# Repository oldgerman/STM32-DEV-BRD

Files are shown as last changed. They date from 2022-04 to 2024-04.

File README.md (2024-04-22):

# STM32-DEV-BRD

（白嫖失败血压升高后）整的几片考究的STM32最小系统板，~~清一色0603~~，确保食用舒适

PCB工程完全开源，提供测试程序，焊接后第一时间可刷入测试

## 型号

- 💚：完工并已验证
- :yellow_heart:：完工但未验证
- :x:：还没画板子

| 更新日期 | 状态 | 开发板型号 | 支持芯片 | PCB层数 |
| --- | --- | --- | --- | --- |
| 2022/04/29 | 💚 | [G031 DEV BRD](https://github.com/oldgerman/STM32-DEV-BRD/tree/master/G031_Dev) | STM32G031G8Ux | 2 |
| 2022/04/29 | 💚 | [F4x1 DEV BRD](https://github.com/oldgerman/STM32-DEV-BRD/tree/master/F4x1_Dev) | STM32F401CxUx<br />STM32F411CxUx | 4 |
| 2022/07/31 | :yellow_heart: | [H7xxVxT6_LANG](https://github.com/oldgerman/STM32-DEV-BRD/tree/master/H7xxVxT6_LANG) | （LQFP100）<br />STM32H750<br />STM32H743<br />STM32H7B0 | 2 |
| ? | :x: | F07x DEV BRD | STM32F071CxUx<br />STM32F072CxUx | ? |
| ? | :x: | F103 DEV BRD | STM32F103CxUx | ? |
| 2024/02/29 | 💚 | [G431 DEV BRD](https://github.com/oldgerman/STM32-DEV-BRD/tree/master/G431_Dev) | STM32G431GBUx | 4 |
| ? | ... | （不定期更新） | | |

## PCB

| 开发板型号 | Top | Bottom |
| --- | --- | --- |
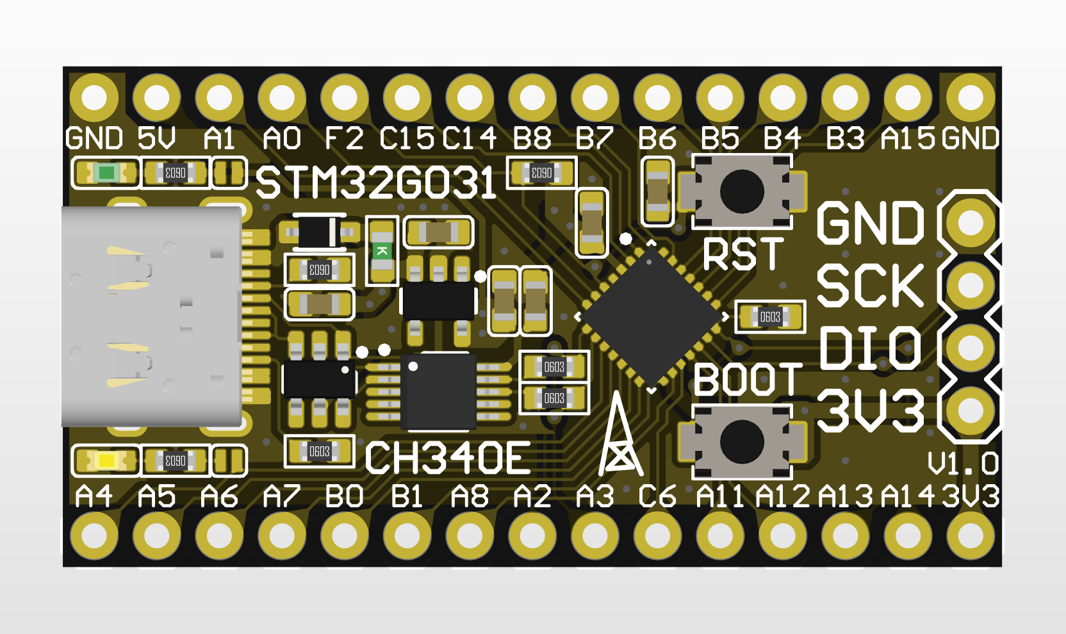
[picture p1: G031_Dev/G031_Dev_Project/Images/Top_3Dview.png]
Top_3Dview
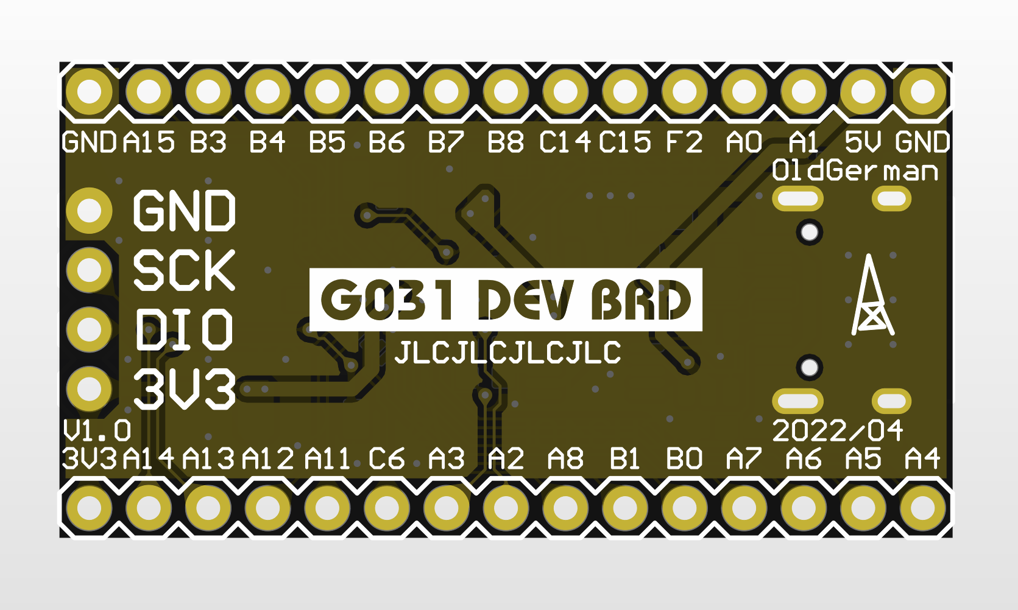
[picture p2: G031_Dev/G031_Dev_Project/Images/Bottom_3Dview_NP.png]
Bottom_3Dview_NP
| G031 DEV BRD |  |  |
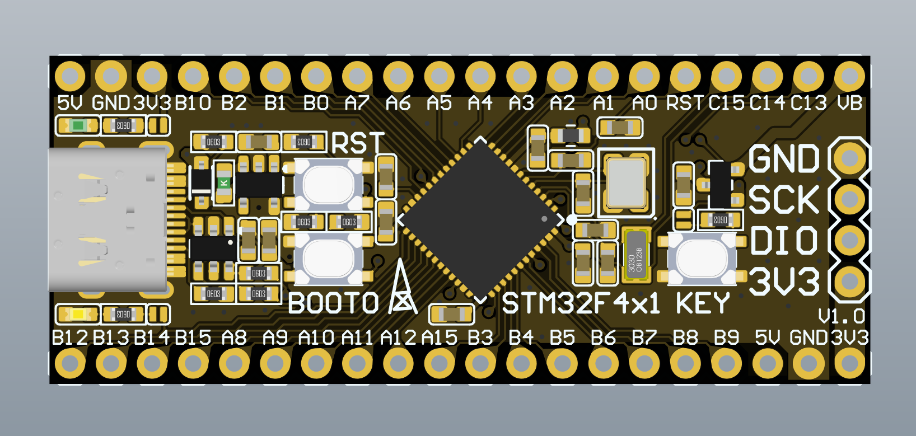
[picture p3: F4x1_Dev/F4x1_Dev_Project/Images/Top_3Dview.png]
Top_3Dview
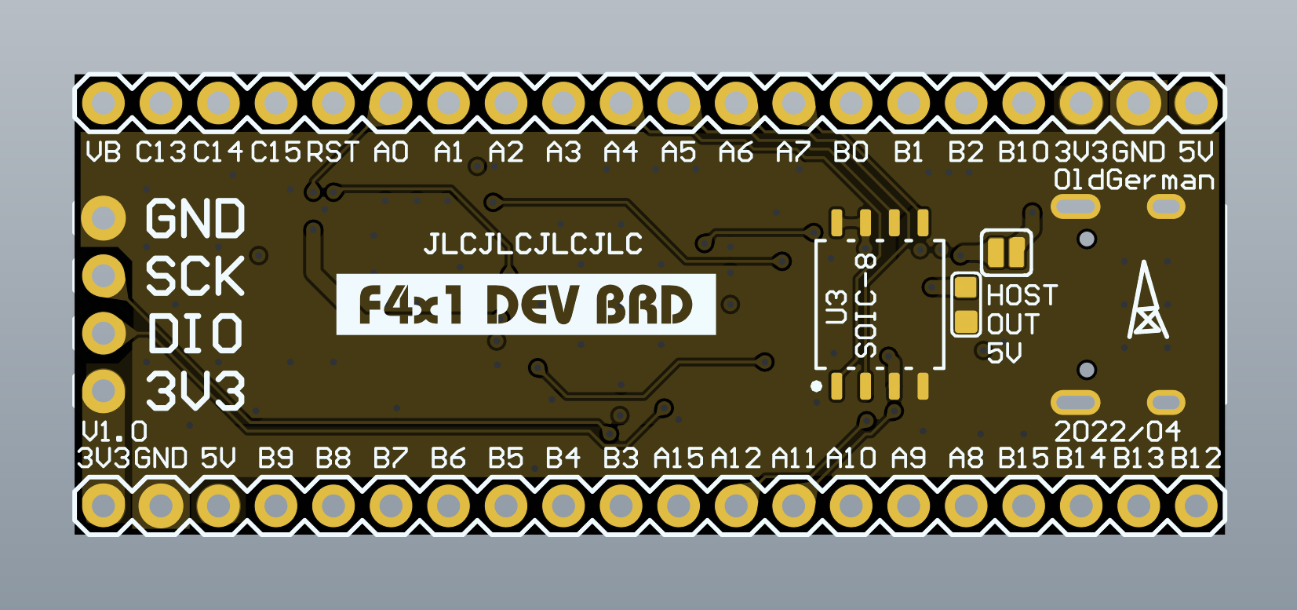
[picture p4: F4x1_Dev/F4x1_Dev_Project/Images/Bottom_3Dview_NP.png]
Bottom_3Dview_NP
| F4x1 DEV BRD |  |  |
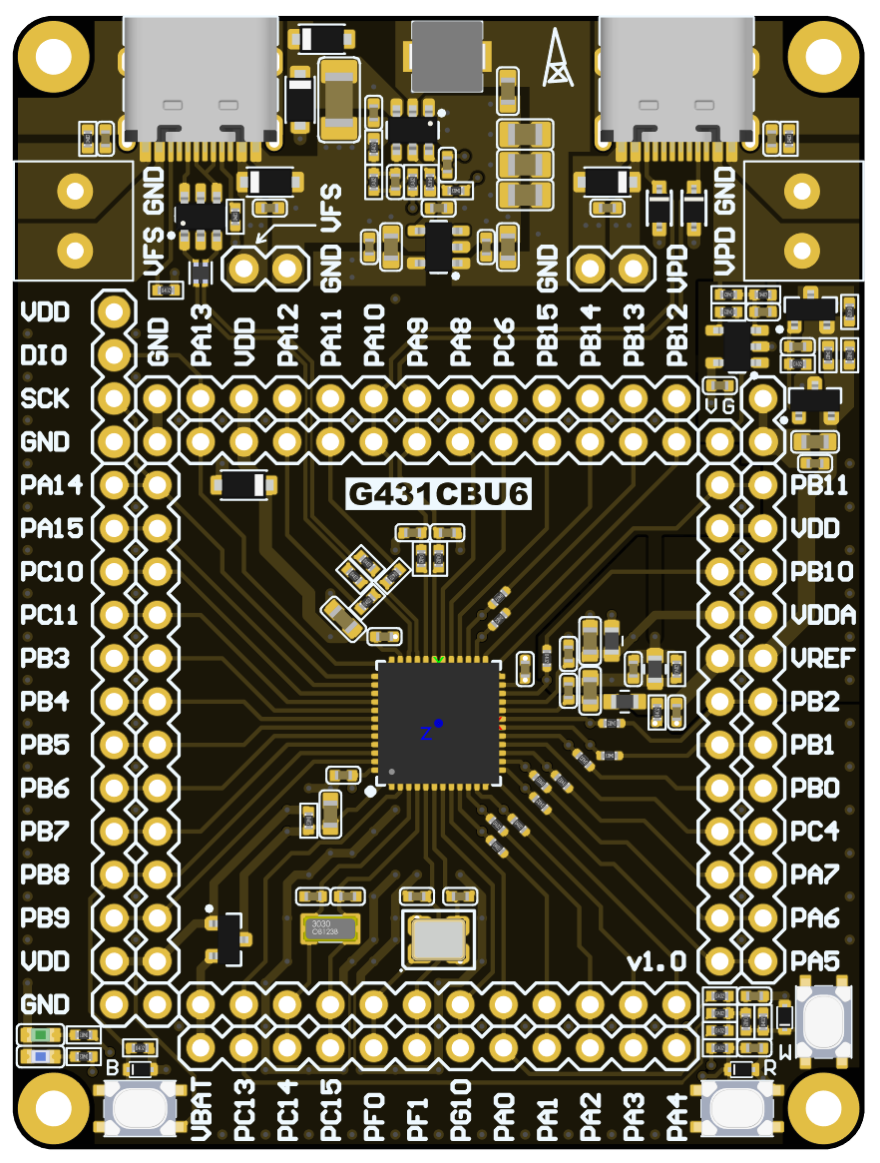
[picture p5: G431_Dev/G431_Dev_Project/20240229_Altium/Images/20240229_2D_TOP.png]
20240229_2D_TOP
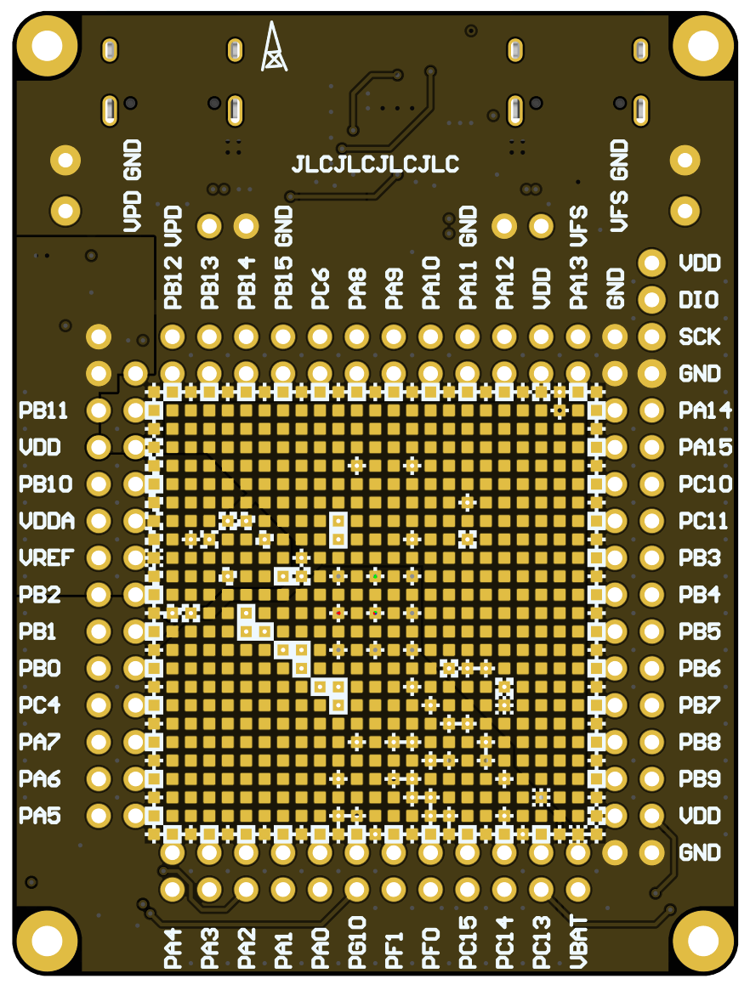
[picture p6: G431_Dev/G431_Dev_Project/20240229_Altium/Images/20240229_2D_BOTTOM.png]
20240229_2D_BOTTOM
| G431 DEV BRD |  |  |

## 图片

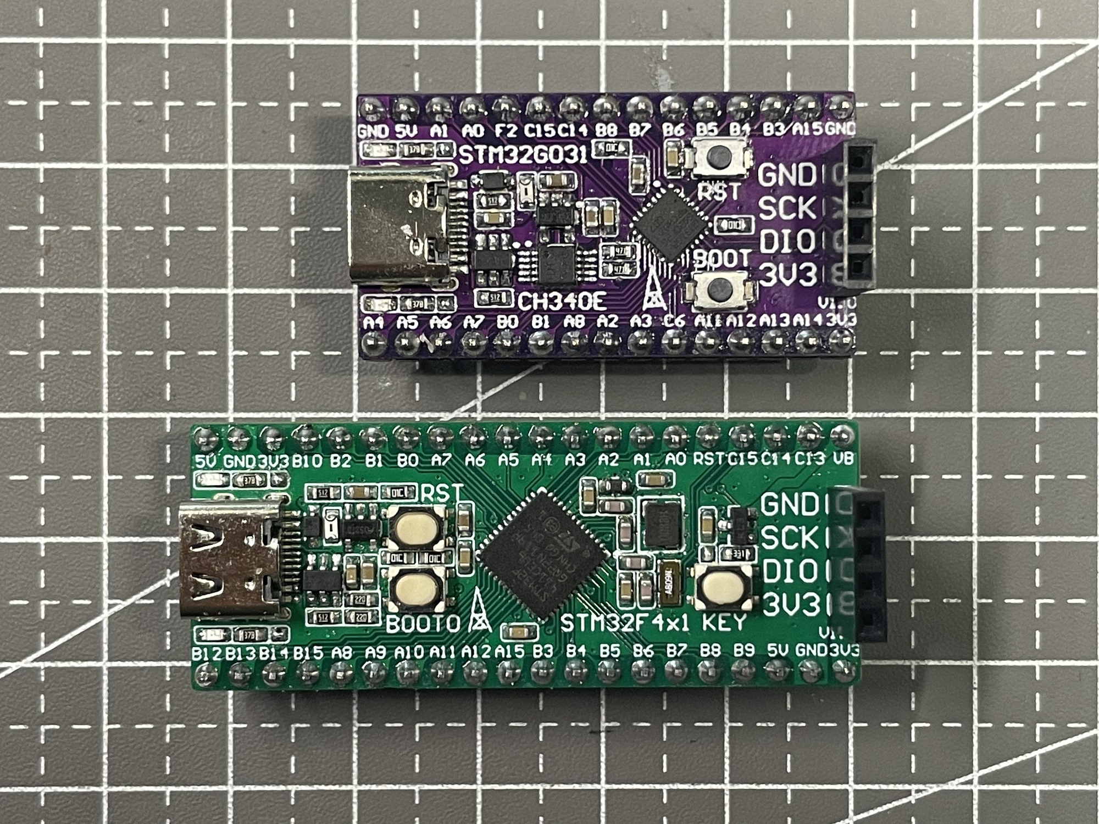
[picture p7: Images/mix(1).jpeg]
mix(1)


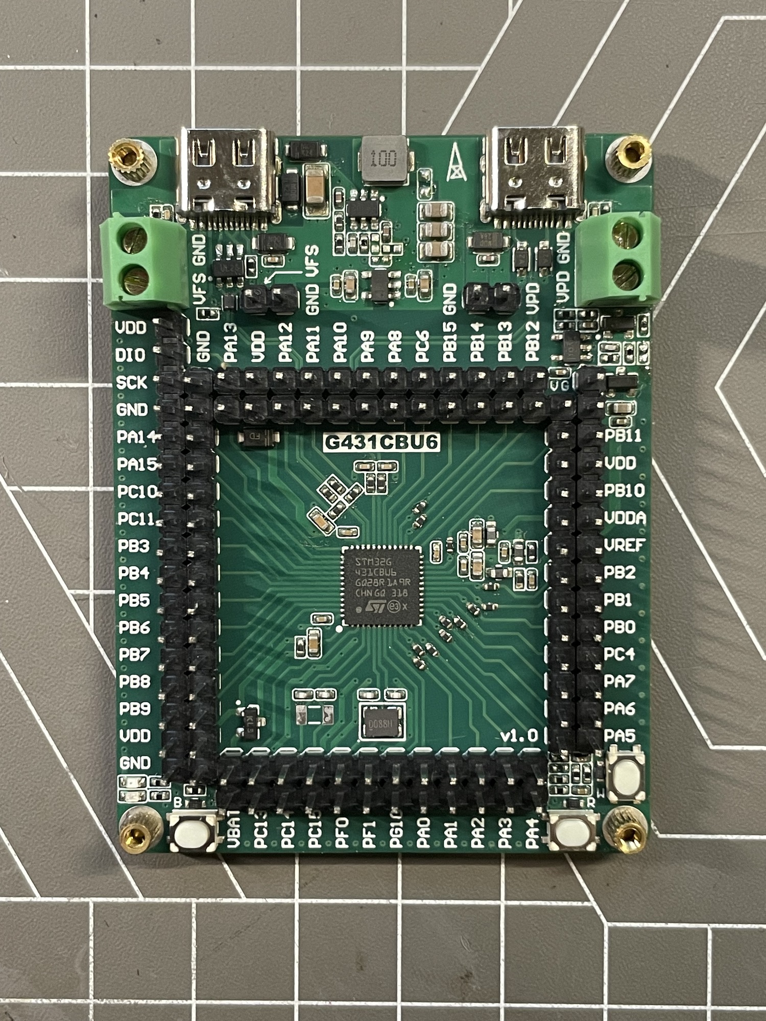
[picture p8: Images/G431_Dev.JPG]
G431_Dev


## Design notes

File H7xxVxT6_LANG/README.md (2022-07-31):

## STM32H750VBT6 核心板

### 原作信息

- 作者：[憂鬱的樹袋熊](https://space.bilibili.com/14536820)
- 立创开源广场：[仿制反客科技STM32H750VBT6核心板](https://oshwhub.com/yydsdx/stm32h750vbt6_gfx)
- 焊接测试视频：[焊个板板，好烫烫！！！ STM32H750开发板](https://www.bilibili.com/video/BV1jU4y1M7GA?share_source=copy_web&vd_source=e6ad3ca74f59d33bf575de5aa7ceb52e)

### 关于

- 两层板设计，过孔0.3/0.5，最小线宽线隙5mil

- 使用贴片双排2.54mm排针排母连接，类似BTB结构

- 从反客科技的板子修改（两个Flash、RGB屏液晶接口、3个按键（复位、BOOT、用户）、1个用户LED、1个TF卡、串口、SWD接口一个都不少）

- 采用MP2144 1.5A DCDC供电3.3V，替代反客科技的SOT-89封装的LDO

- PCB尺寸：65mmx43mm

  孔距：59mx37mm

  两组2x10pin排针：关于板子中心对称，Y方向距离15mm，x坐标为板长中线32.5mm

### 修改部分

> 原作版布线十分潇洒，但德国精工觉得还可以优化，遂做了以下修改

- 更改同步降压DCDC芯片MP2144的布局，与MPS官方手册一致，电感封装由2016改为2520

- 优化大部分走线与焊盘间的45度夹角

- 调整部分盘下孔位置

- 修改固定孔，可完美安装M3 304薄头内六角螺丝

- 更改SWD调试接口的pin顺序

  > （顺序由上到下）
  >
  > 原版为 GND、RST、SWDIO、SWCLK
  >
  > 修改后的顺序为RST、SWDIO、SWCLK、GND
  >
  > 与Blue Pill或者Black Pill的SWD接口：GND、SCK、DIO、3V3为逆向，但3V3换为RST，（实际通过一个10K电阻串联H750的RST）
  >
  > 因此可以直连mini ST-link的4脚：3V3、DIO、SCK、GND

- 更改SN74LVC2G17的封装，从SC-70改为SOT23-6，因为前者涨价了十几倍，后者1元不到
- 更改正面竖向丝印的朝向、位置等，背面丝印添加信仰LOGO

### 修改版图片

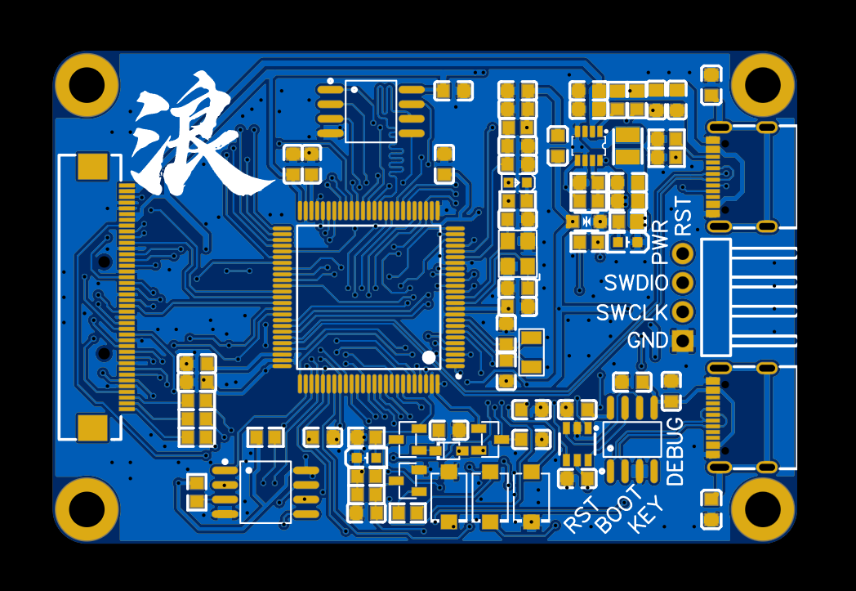
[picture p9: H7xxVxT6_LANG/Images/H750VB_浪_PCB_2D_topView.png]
H750VB_浪_PCB_2D_topView
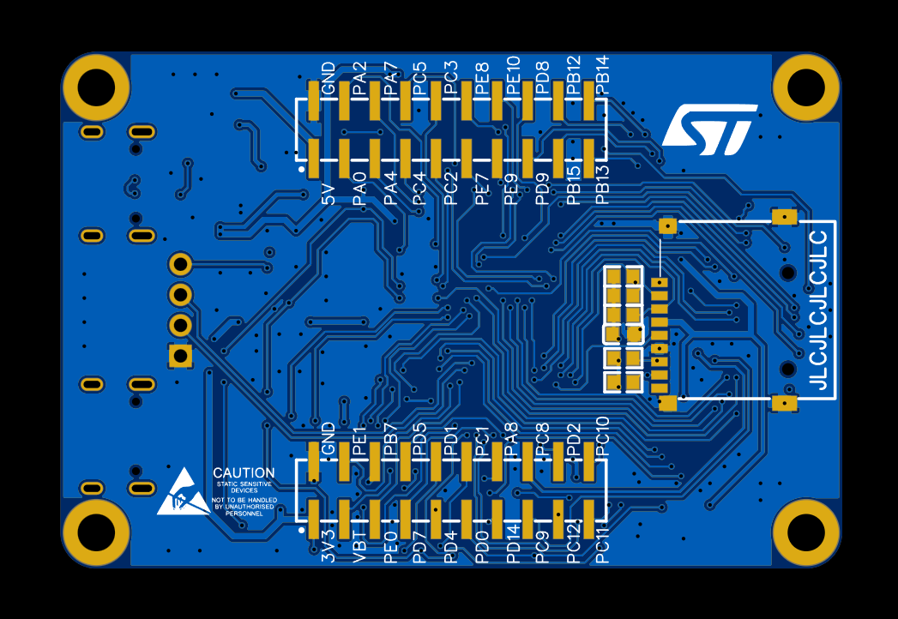
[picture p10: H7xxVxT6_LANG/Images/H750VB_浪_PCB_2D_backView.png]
H750VB_浪_PCB_2D_backView
|  |  |
| --- | --- |

### 底板母座引出的io 对比 反客科技

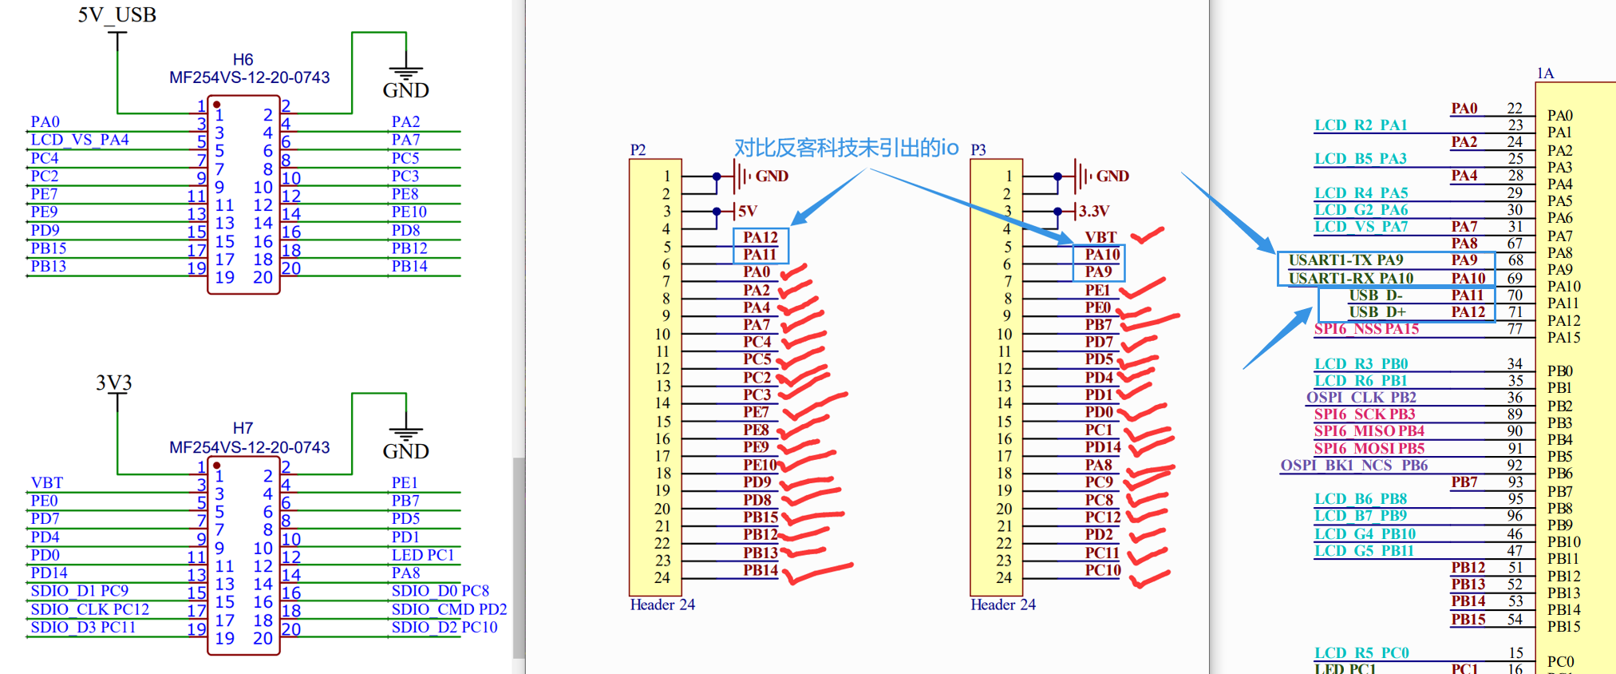
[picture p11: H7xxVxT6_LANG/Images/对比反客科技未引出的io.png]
对比反客科技未引出的io


### 引出io对应的CubeMX脚位

[本图CubeMX文件](https://github.com/oldgerman/STM32-DEV-BRD/tree/master/H7xxVxT6_LANG/CubeMX/H750VBTx_LANG_BTB_IO)

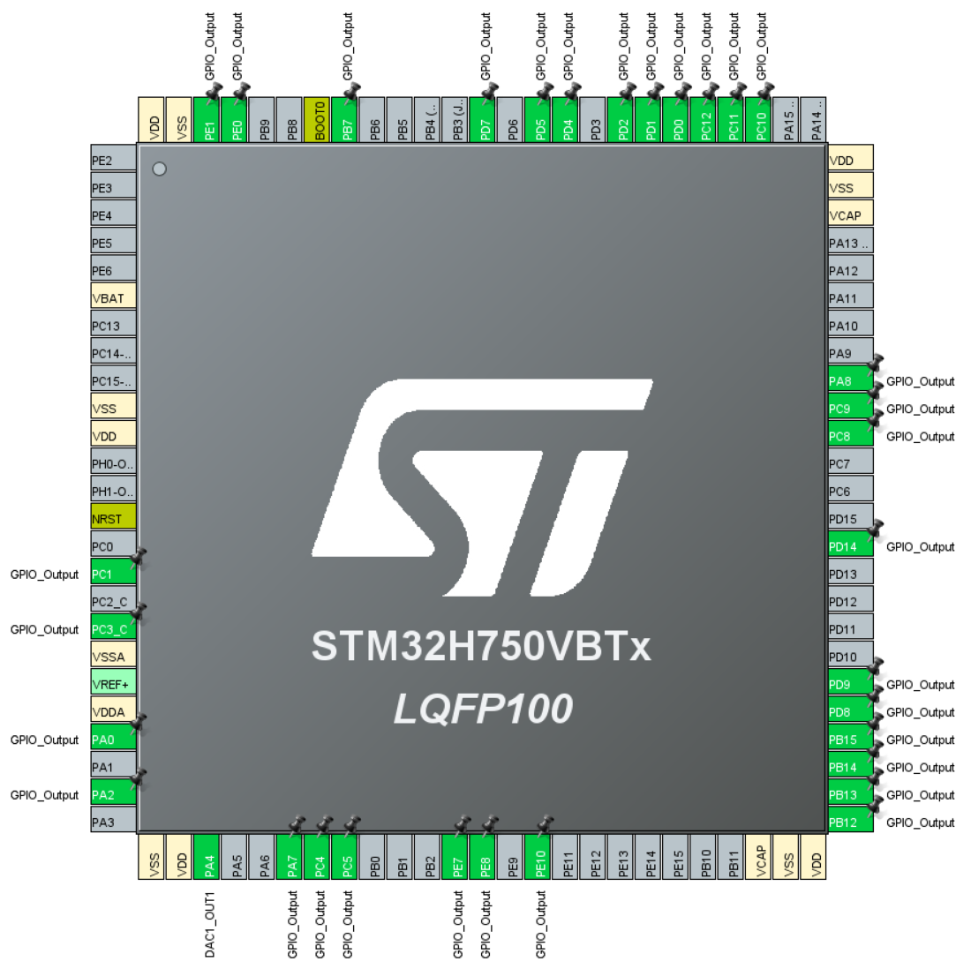
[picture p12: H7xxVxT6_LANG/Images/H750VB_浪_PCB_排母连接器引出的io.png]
H750VB_浪_PCB_排母连接器引出的io


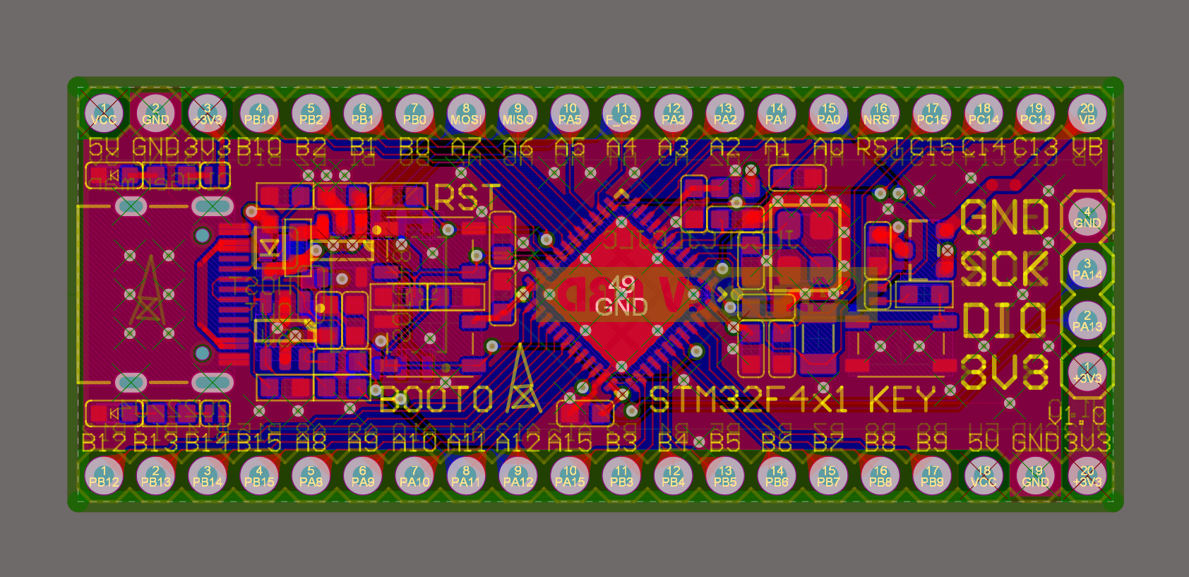
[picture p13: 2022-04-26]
F4x1_Dev/F4x1_Dev_Project/Images/Top_2Dview.png

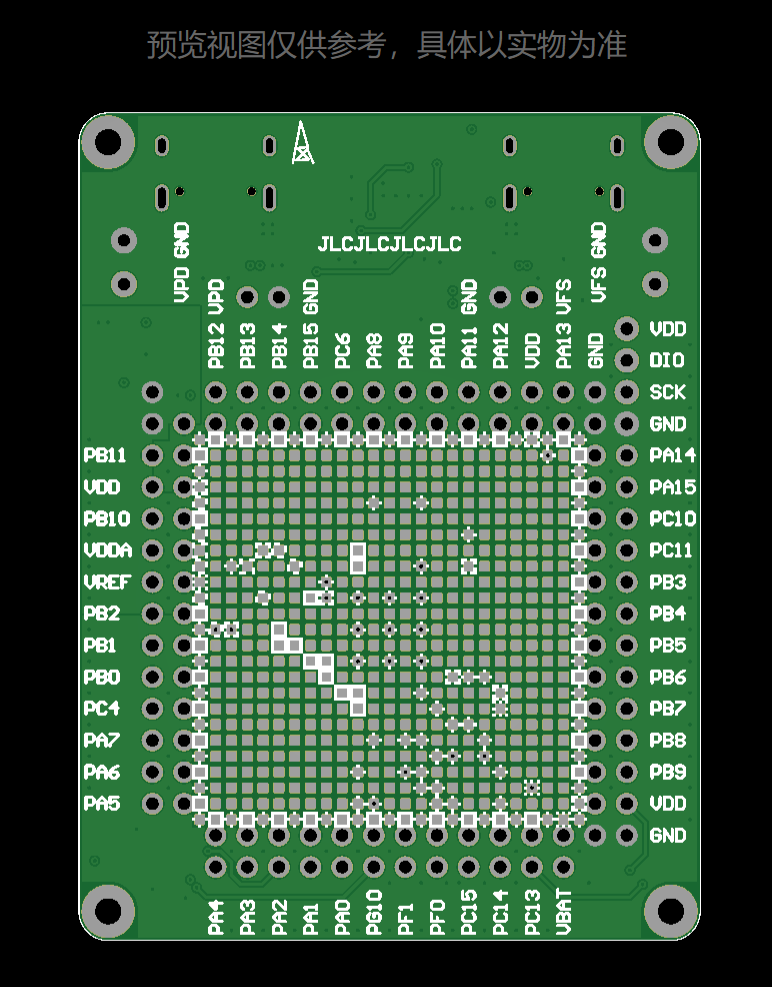
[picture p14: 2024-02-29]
G431_Dev/G431_Dev_Project/20240422_Altium（实际焊接）/Images/JLC_2D_View(2).png

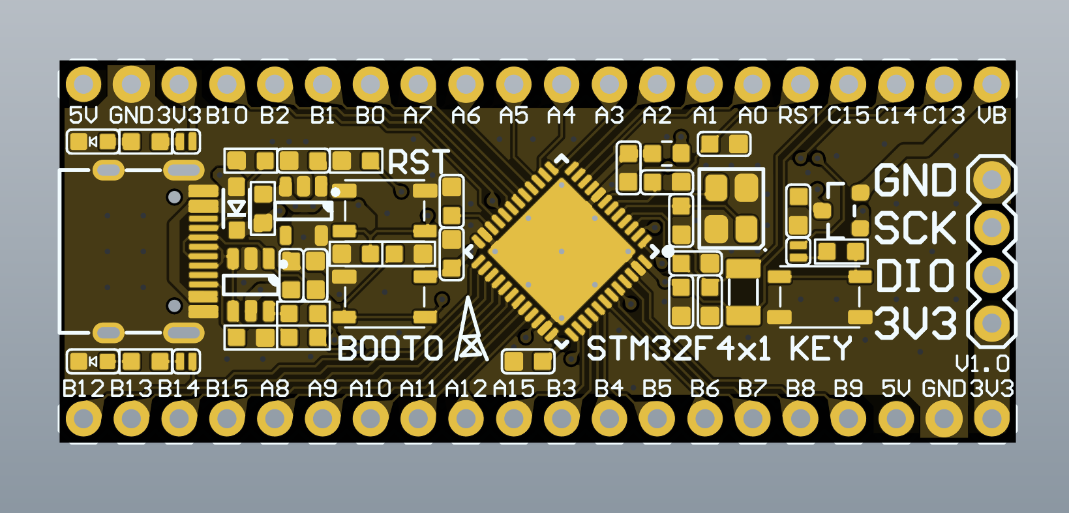
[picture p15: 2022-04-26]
F4x1_Dev/F4x1_Dev_Project/Images/Top_3Dview_NP.png

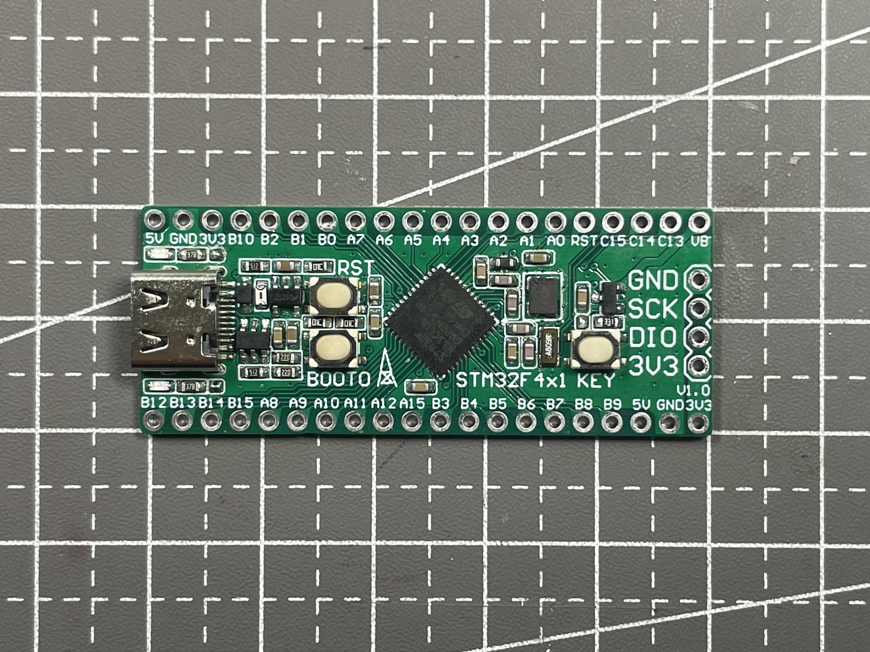
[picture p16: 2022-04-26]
Images/F4x1_DEV_BRD(1).jpeg

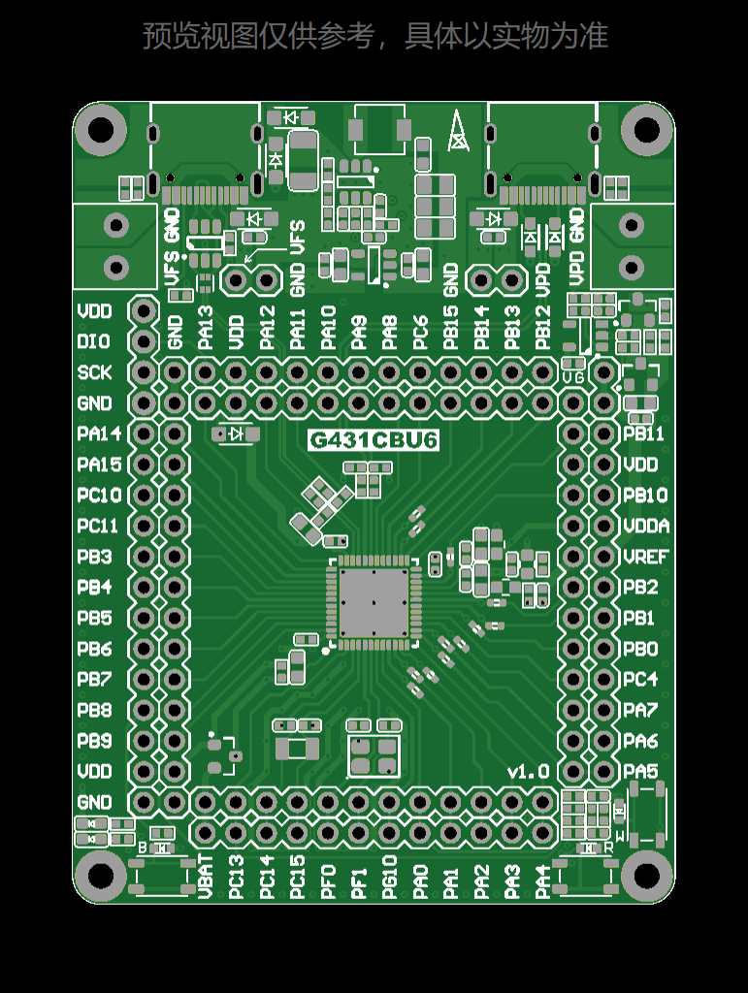
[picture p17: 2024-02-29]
G431_Dev/G431_Dev_Project/20240422_Altium（实际焊接）/Images/JLC_2D_View(1).png

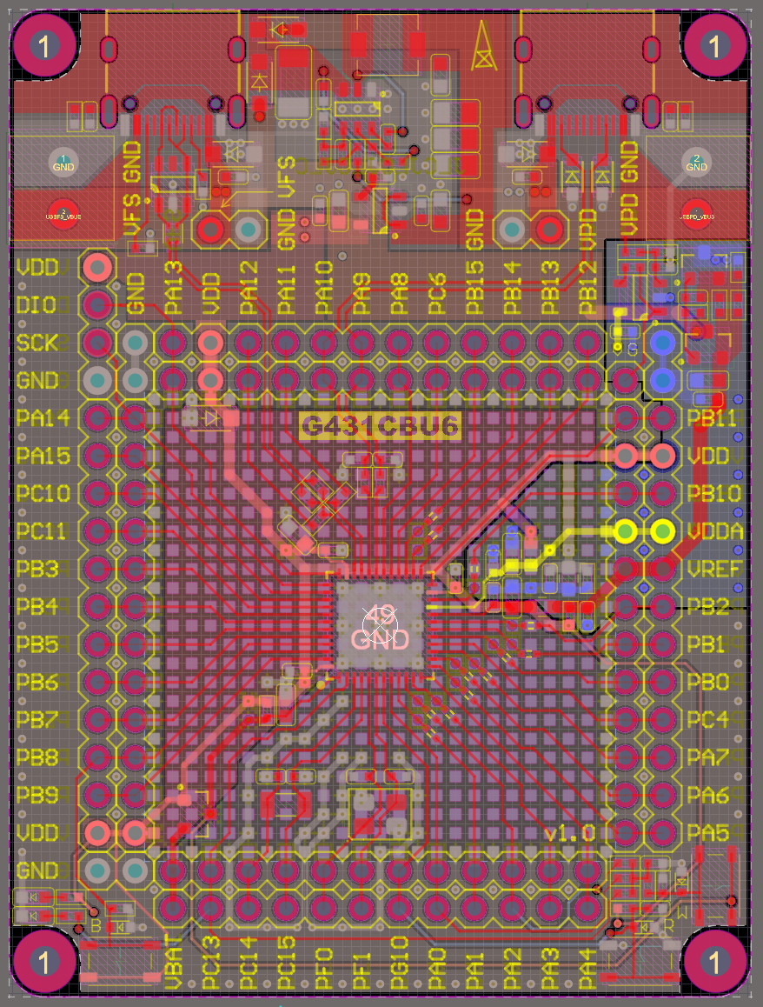
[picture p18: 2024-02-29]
G431_Dev/G431_Dev_Project/20240229_Altium/Images/20240229_1.0.png

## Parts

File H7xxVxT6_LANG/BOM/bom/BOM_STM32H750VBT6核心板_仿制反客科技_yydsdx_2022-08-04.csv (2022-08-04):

ID | Name | Designator | Footprint | Quantity | Manufacturer Part | Manufacturer | Supplier | Supplier Part | Price
1 | 100nF | C1,C2,C3,C4,C5,C6 | C0603 | 6 | CT41G-0603-2X1-50V-0.1μF-K(N) | TORCH | LCSC | C125205 | 0.0376
2 | 22uF | C7 | C0603 | 1 | C1608X5R1E106MT000E | TDK | LCSC | C76614 | 0.1527
3 | 100nF | C9,C11,C14,C15,C17,C18,C19,C20,C25,C28,C29,C30,C31 | C0603 | 13 | 0603B104K160 | WTC | LCSC | C80516 | 0.0236
4 | 22uF | C10 | C0603 | 1 | CL10A226MQ8NRNC | SAMSUNG | LCSC | C59461 | 0.0291
5 | 22uF | C13 | C0603 | 1 | CL10A106KP8NNNC | SAMSUNG | LCSC | C19702 | 0.0191
6 | 10uF | C16 | C0603 | 1 | CL10A106KP8NNNC | SAMSUNG | LCSC | C19702 | 0.0191
7 | 22pF | C21,C22 | C0603 | 2 | 0603B104K160 | WTC | LCSC | C80516 | 0.0236
8 | 12.5pF | C23,C24 | C0603 | 2 | 0603B104K160 | WTC | LCSC | C80516 | 0.0236
9 | 10uF | C26,C27 | C0603 | 2 | 0603B104K160 | WTC | LCSC | C80516 | 0.0236
10 | 2.2uF | C32,C33 | C0603 | 2 | 0603B104K160 | WTC | LCSC | C80516 | 0.0236
11 | TF-01A | CARD1 | TF-SMD_TF-01A | 1 | TF-01A | HRO | LCSC | C91145 | 1.0231
12 | PESD3V3L1BA-N | D2 | SOD-323_L1.8-W1.3-LS2.5-BI | 1 | PESD3V3L1BA-N | Bourne Semicon (Shenzhen) | LCSC | C316020 | 0.3041
13 | BAT54C_C556168 | D3 | SOT-23-3_L2.9-W1.3-P1.90-LS2.4-BR | 1 | BAT54C | Slkor(SLKORMICRO Elec.) | LCSC | C556168 | 0.0809
14 | 1N4007WS | D5 | SOD-323_L1.8-W1.3-LS2.5-RD | 1 | 1N4007WS | (MDD) Jiangsu Yutai Elec | LCSC | C193404 | 0.181
15 | F0502-B-40-20T-R | FPC1 | FPC-SMD_40P-P0.50 | 1 | F0502-B-40-20T-R | XFCN | LCSC | C481222 | 0.896
16 | 定位孔 | H1,H2,H3,H4 | 定位孔 | 4
17 | 2.54-1*4P反弯排针 | H5 | HDR-TH_4P-P2.54-H-M-W10.4 | 1 | 2.54-1*4P反弯排针 | BOOMELE(博穆精密) | LCSC | C91552 | 0.1395
18 | MF254VS-12-20-0743 | H6,H7 | HDR-SMD_20P-P2.54-V-F-R2-C10-S2.54-LS7.2 | 2 | MF254VS-12-20-0743 | XFCN | LCSC | C512909 | 2.69
19 | 1uH | L1 | IND-SMD_L2.5-W2.0_SLW252012P2R2MST | 1 | SLW252012P1R0MST | 3L COILS | LCSC | C326032 | 0.7258
20 | 330Ω@100MHz | L2,L3,L6 | L0603 | 3 | SZ1608K331TF | Sunlord | LCSC | C96990 | 0.0305
21 | green | LED1,LED3 | LED0603-R-RD | 2 | ORH-G36G | Orient | LCSC | C205443 | 0.0709
22 | blue | LED2 | LED0603-RD | 1 | MHT192WDT-ICE | MEIHUA | LCSC | C389522 | 0.2394
23 | SS8050 | Q1,Q2 | SOT-23-3_L2.9-W1.3-P1.90-LS2.4-BR | 2 | SS8050 | CJ | LCSC | C2150 | 0.0976
24 | 200K | R1,R20 | R0603 | 2 | RTT032003FTP | RALEC | LCSC | C103392 | 0.0074
25 | 44.2K | R2 | R0603 | 1 | 0603WAF4422T5E | UniOhm | LCSC | C23056 | 0.0088
26 | 1K | R3,R11,R12,R29 | R0603 | 4 | WR06X1001FTL | WTC | LCSC | C112433 | 0.0069
27 | 10k | R4,R5,R6,R7,R8,R9,R15,R18,R23 | R0603 | 9 | RTT032003FTP | RALEC | LCSC | C103392 | 0.0074
28 | 0R | R10 | R0603 | 1 | WR06X1001FTL | WTC | LCSC | C112433 | 0.0069
29 | 120R | R13,R14 | R0603 | 2 | WR06X1001FTL | WTC | LCSC | C112433 | 0.0069
30 | 1k | R16,R17 | R0603 | 2 | RTT032003FTP | RALEC | LCSC | C103392 | 0.0074
31 | 499K | R19 | R0603 | 1 | RTT032003FTP | RALEC | LCSC | C103392 | 0.0074
32 | 5K1 | R118,R119 | R0603 | 2 | WR06X1001FTL | WTC | LCSC | C112433 | 0.0069
33 | SKRKAEE020 | SW1,SW2,SW4 | SW-SMD_L3.9-W3.0-P4.45 | 3 | SKRKAEE020 | ALPS | LCSC | C115357 | 0.661
34 | STM32H750VBT6 | U1 | LQFP-100_L14.0-W14.0-P0.50-LS16.0-BL | 1 | STM32H750VBT6 | STMicroelectronics | LCSC | C404010 | 121.24
35 | MP2144GJ | U2 | TSOT-23-8_L2.9-W1.6-P0.65-LS2.8-BL | 1
36 | W25Q64JVSSIQ | U3,U4 | SOP-8_L5.3-W5.3-P1.27-LS8.0-BL | 2 | W25Q64JVSSIQ | WINBOND | LCSC | C83140 | 3.67
37 | CH340N | U5 | SOP-8_L5.0-W4.0-P1.27-LS6.0-BL | 1 | CH340N | WCH(Jiangsu Qin Heng) | LCSC | C506813 | 3.17
38 | SN74LVC2G17DBVR | U7 | SOT-23-6_L2.9-W1.6-P0.95-LS2.8-BR | 1 | SN74LVC2G17DBVR | TI | LCSC | C10429 | 0.8936
39 | TYPE-C16PIN | USB1,USB2 | USB-C-SMD_TYPE-C16PIN | 2 | TYPE-C16PIN | SHOU HAN | LCSC | C393939 | 1.5593
40 | 25MHz | X1 | OSC-SMD_4P-L3.2-W2.5-BL | 1 | X322512MSB4SI | YXC | LCSC | C9002 | 0.5056
41 | 32.768KHz | X2 | OSC-SMD_L3.2-W1.5 | 1 | SF32K32768D31T-12.5 | TKD | LCSC | C271654 | 1.4058

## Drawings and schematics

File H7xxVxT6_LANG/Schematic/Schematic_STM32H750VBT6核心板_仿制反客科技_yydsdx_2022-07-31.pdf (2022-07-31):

3V3

GND | GND GND

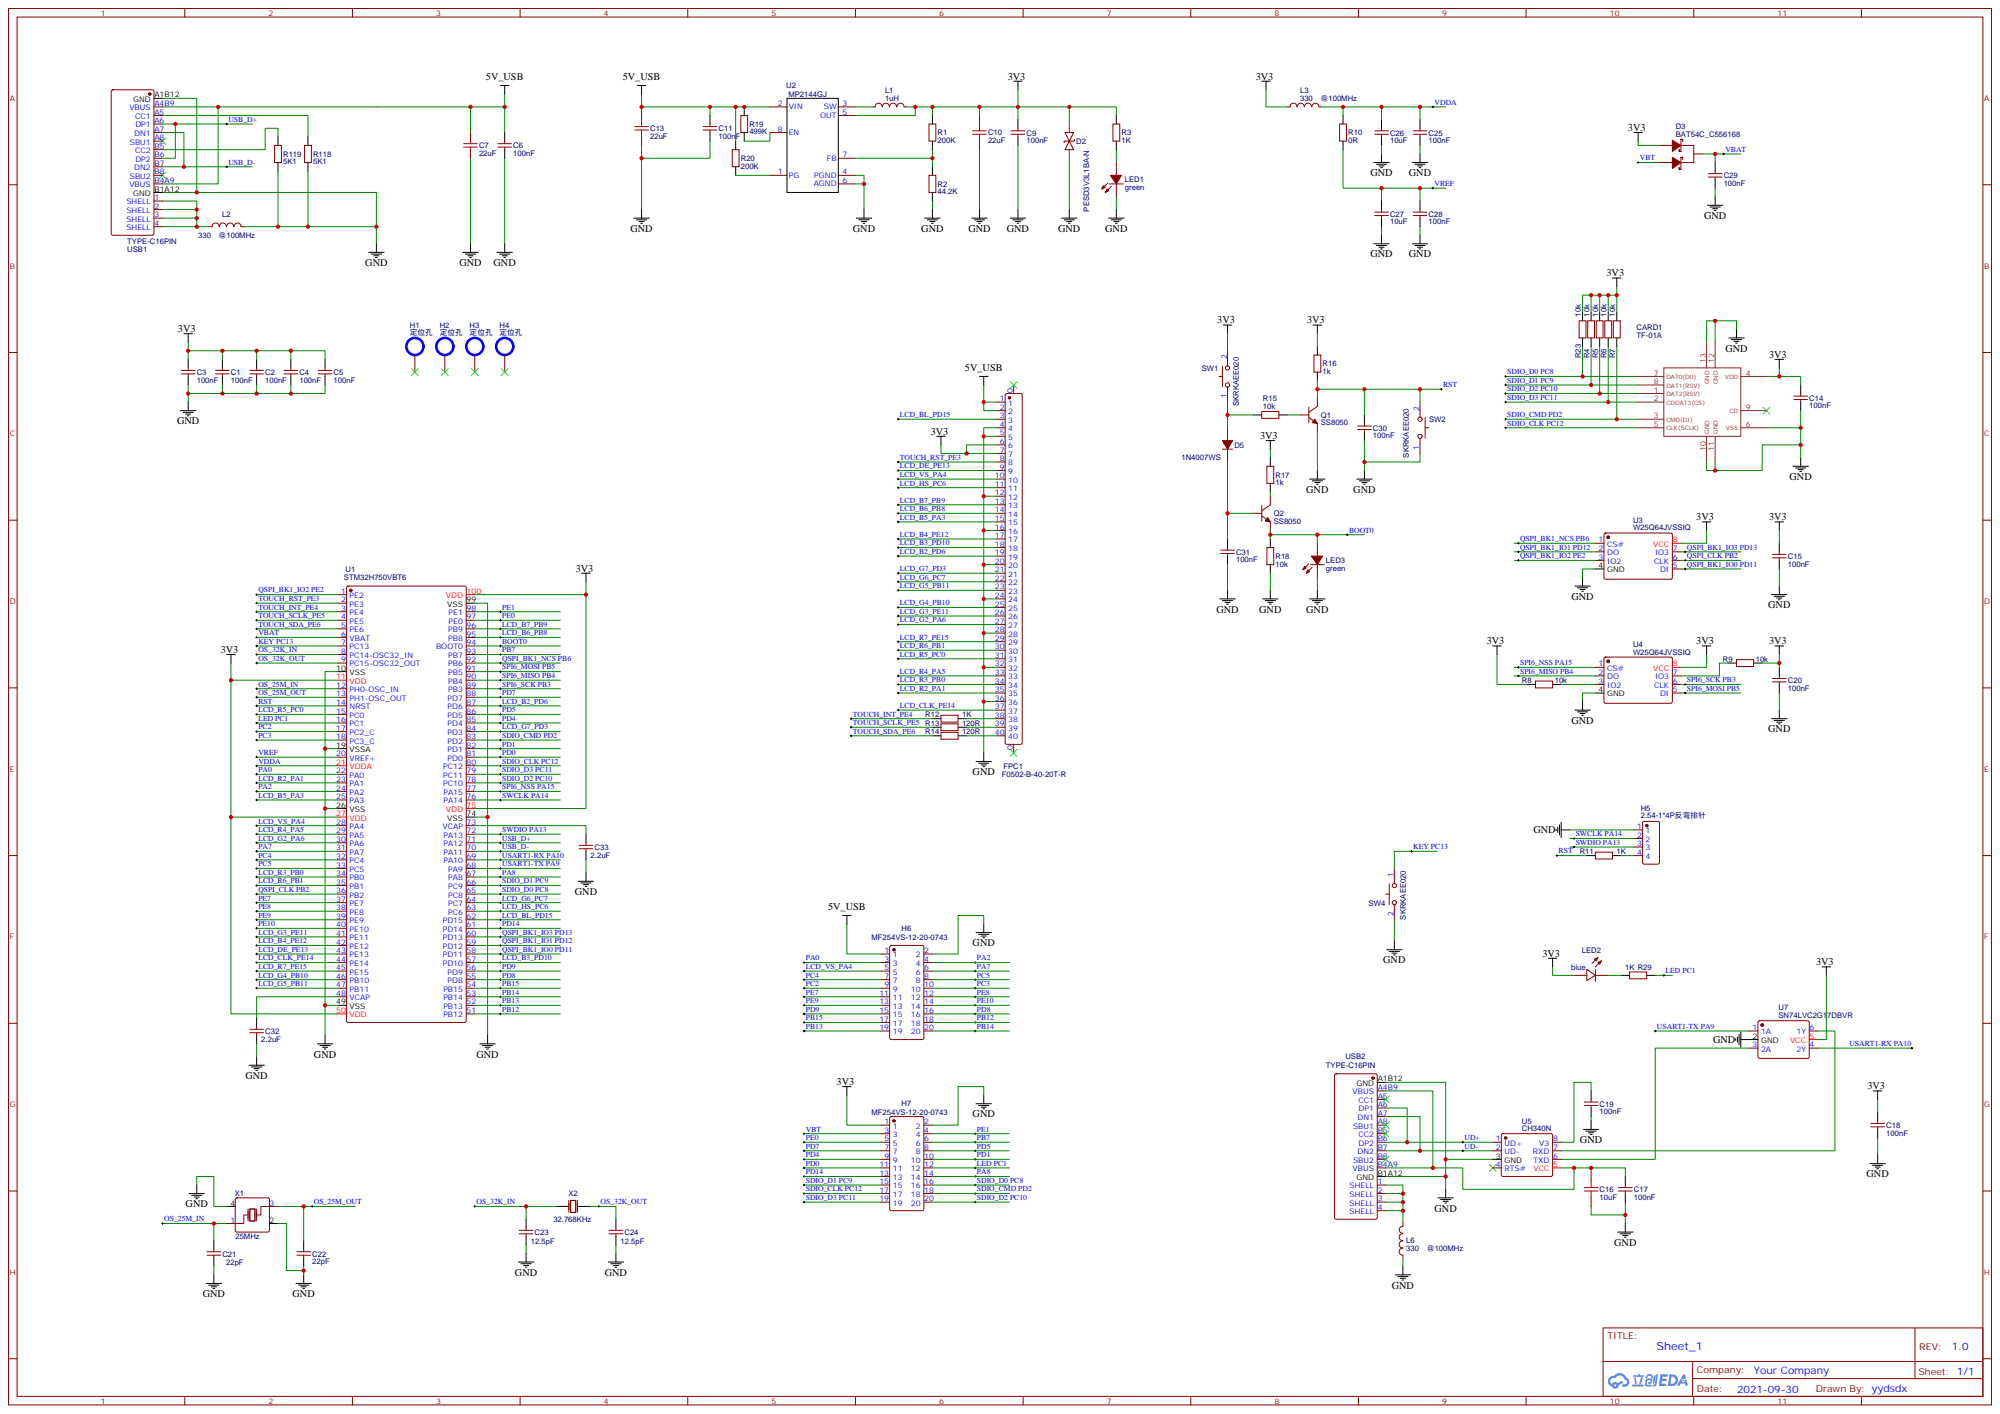
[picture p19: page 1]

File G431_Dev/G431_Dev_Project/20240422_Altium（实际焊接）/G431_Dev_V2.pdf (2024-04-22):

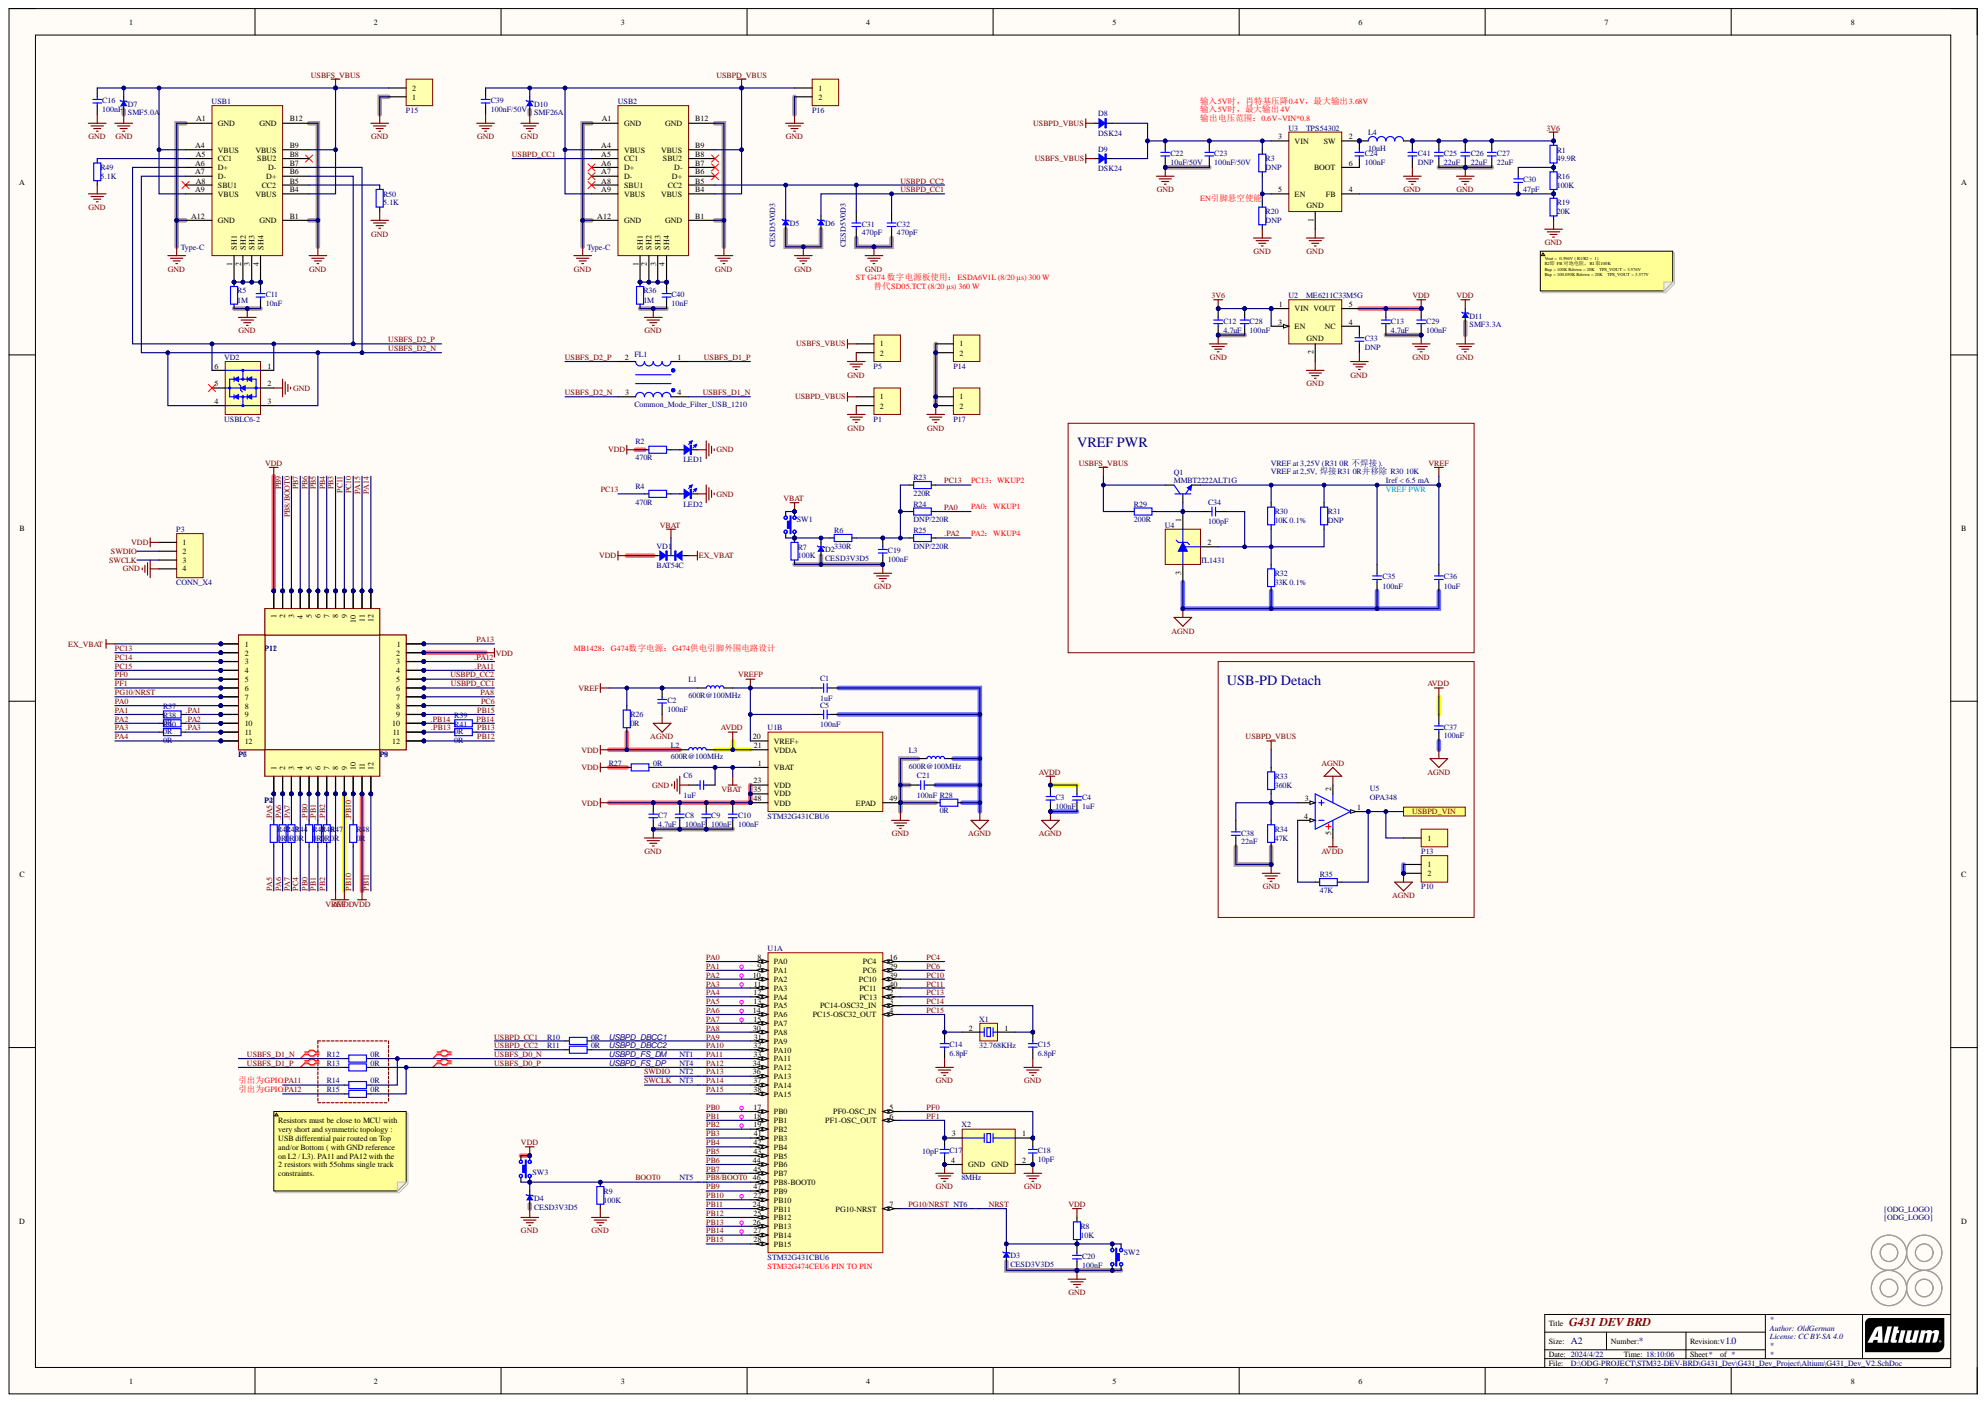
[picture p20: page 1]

Resistors must be close to MCU with
very short and symmetric topology :
USB differential pair routed on Top
and/or Bottom ( with GND reference
on L2 / L3). PA11 and PA12 with the
2 resistors with 55ohms single track
constraints.

D:\ODG-PROJECT\STM32-DEV-BRD\G431_Dev\G431_Dev_Project\Altium\G431_Dev_V2.SchDoc

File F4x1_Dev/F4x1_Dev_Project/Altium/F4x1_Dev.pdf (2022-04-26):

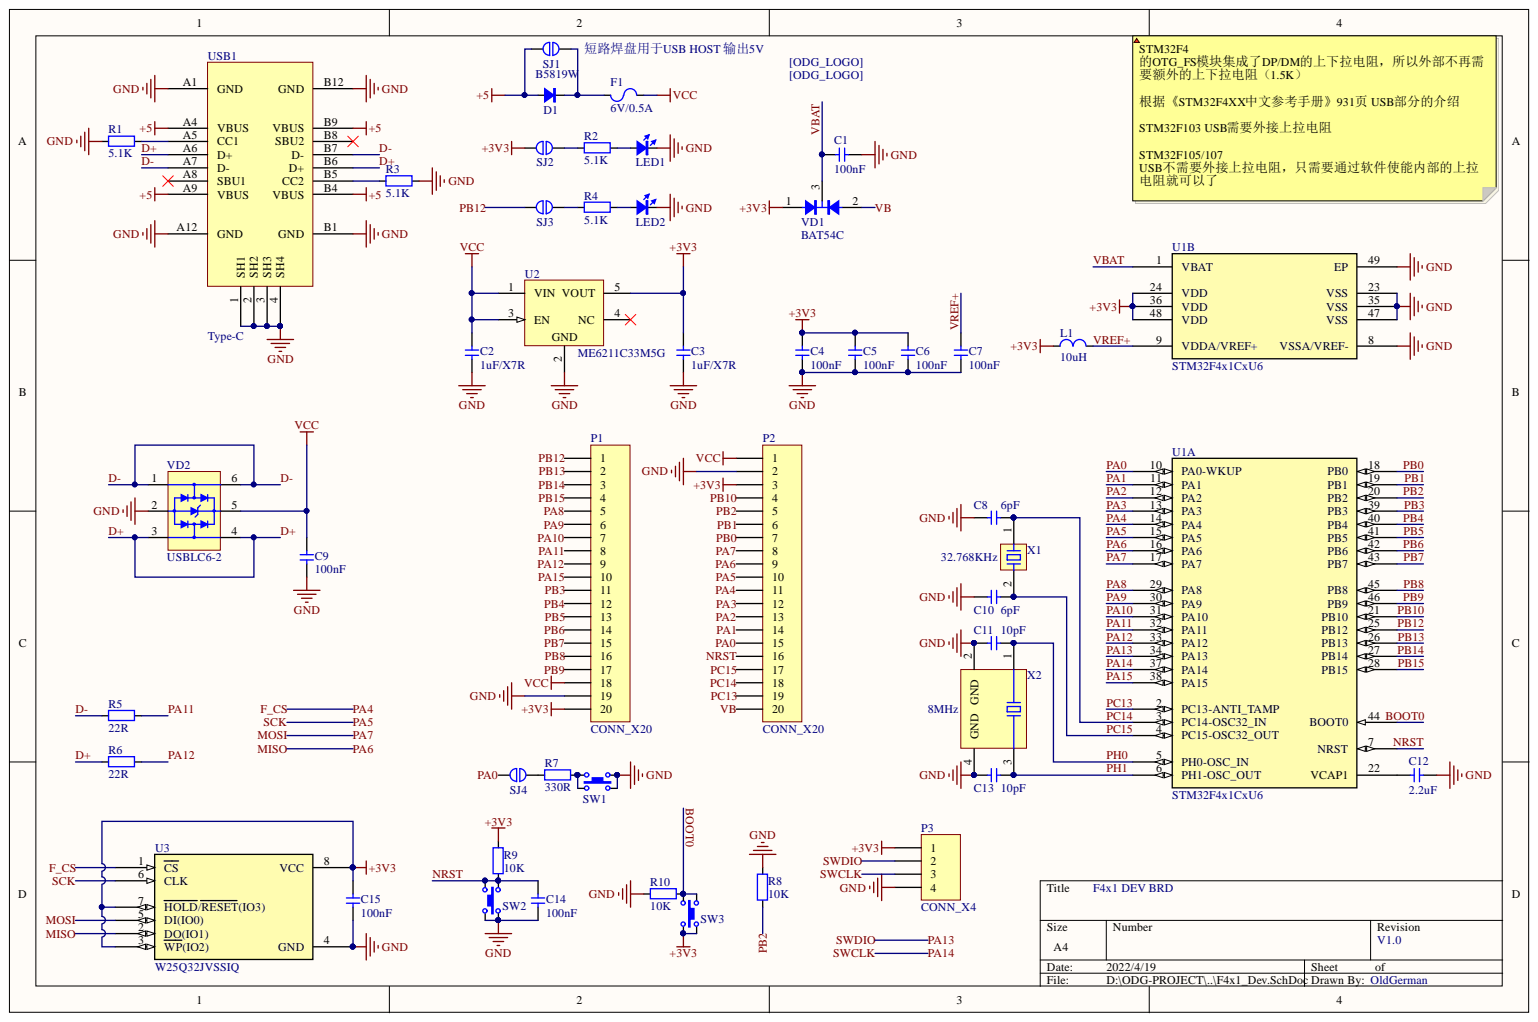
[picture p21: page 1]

PC15 | PC15-OSC32_OUT 4

PH0 | | PH0-OSC_IN 5

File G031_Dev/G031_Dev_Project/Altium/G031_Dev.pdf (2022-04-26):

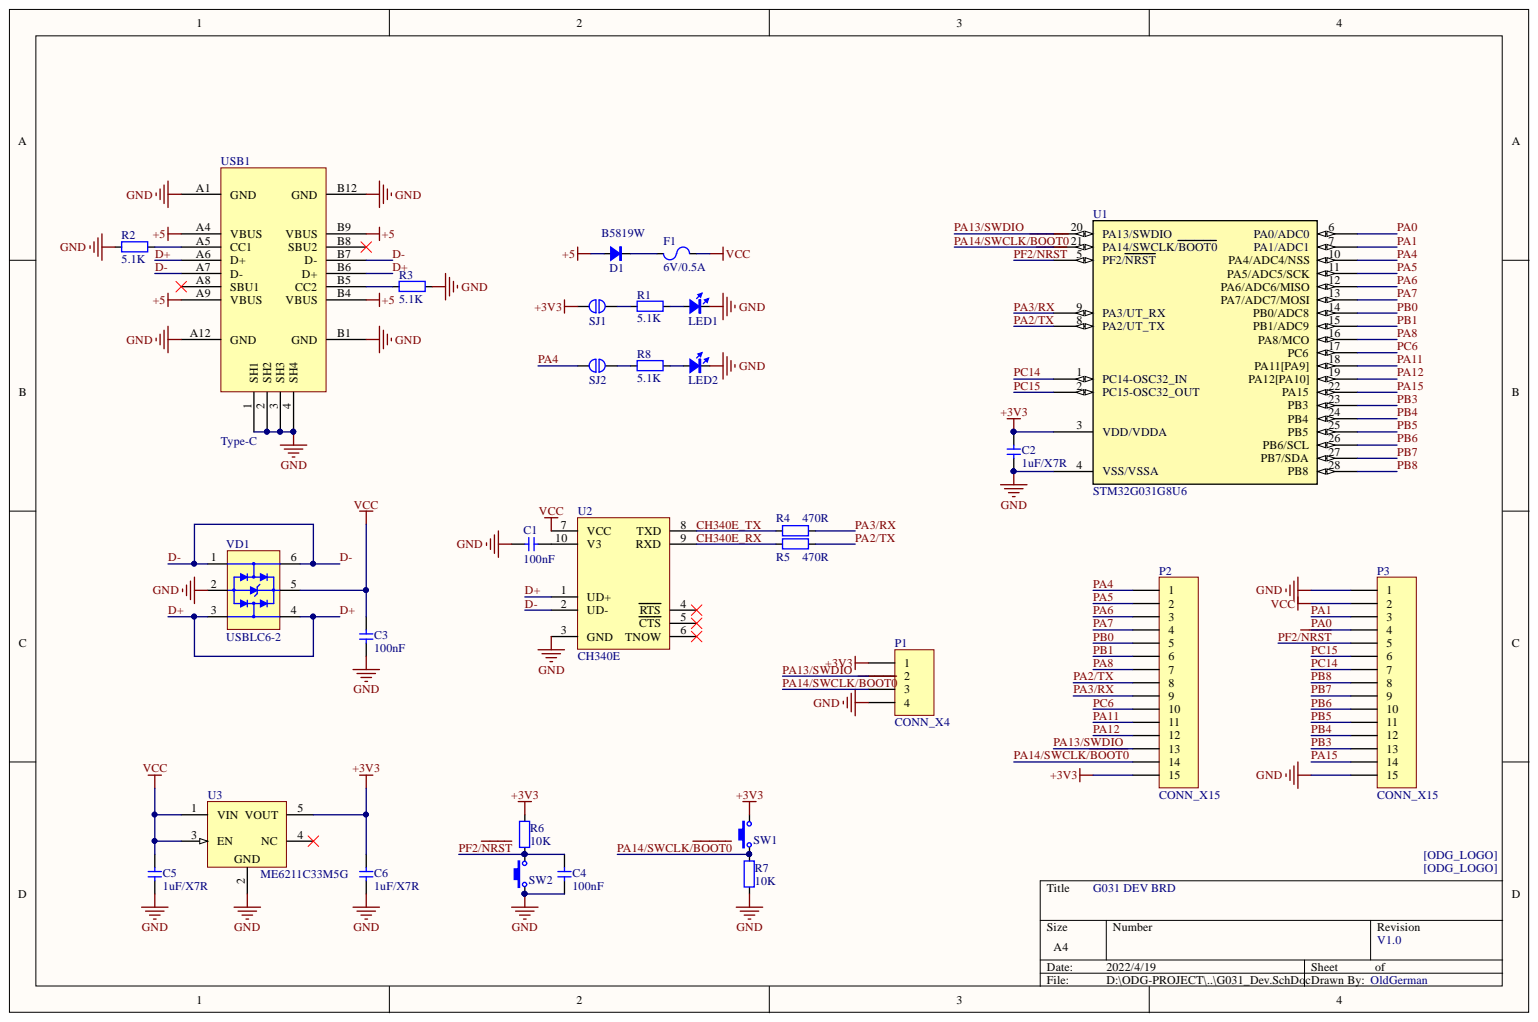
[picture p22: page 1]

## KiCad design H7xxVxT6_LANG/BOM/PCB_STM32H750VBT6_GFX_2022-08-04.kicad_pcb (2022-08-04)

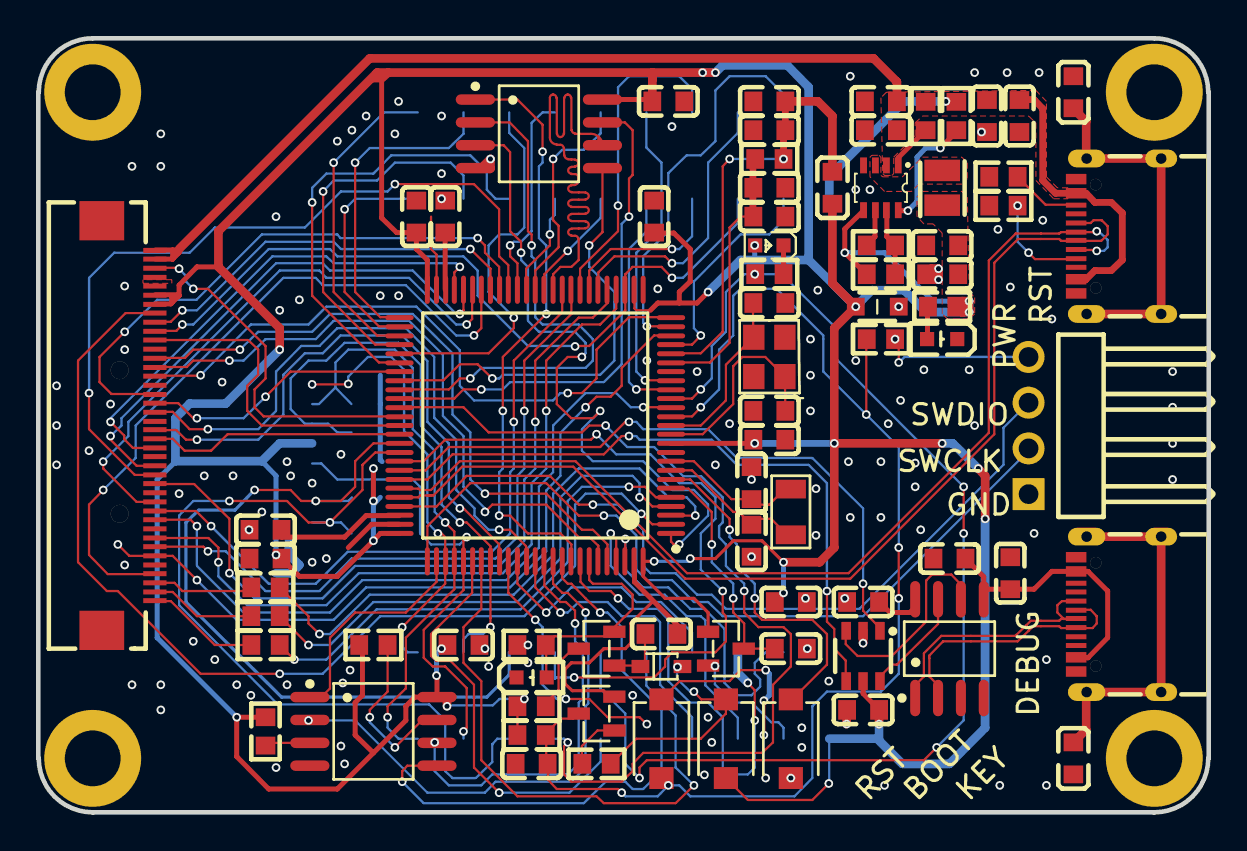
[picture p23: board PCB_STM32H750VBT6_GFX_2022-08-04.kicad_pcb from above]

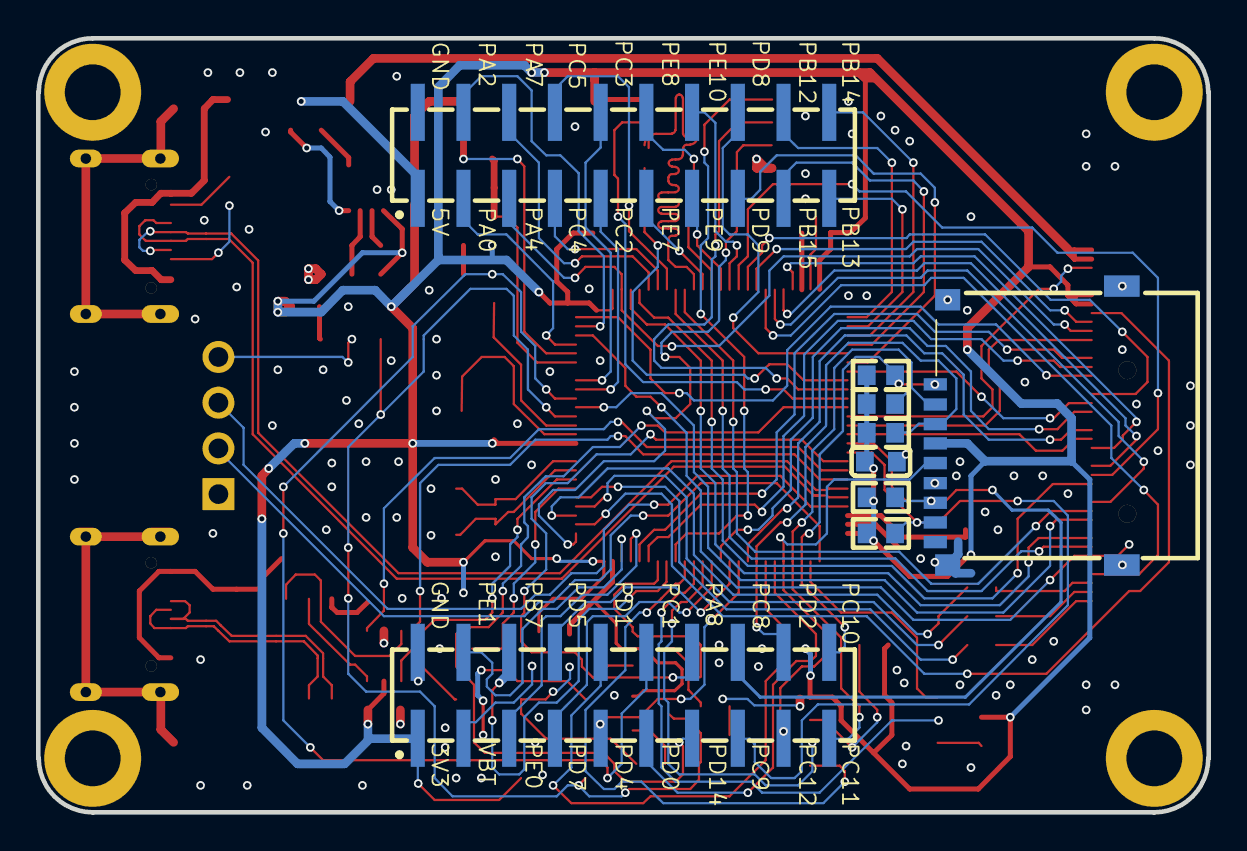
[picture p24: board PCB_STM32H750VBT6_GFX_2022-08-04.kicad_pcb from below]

Board: 2 copper layers, 65.0 x 43.0 mm, 92 parts (9 on the bottom side), 119 nets.

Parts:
C1, C2, C3, C4, C5, C6, C9, C11, C15, C17, C18, C19, C20, C25, C28, C29, C30, C31: 100nF; C0603_1
C7, C10, C13: 22uF; C0603_1
C14: 100nF; C0603_2
C16, C26, C27: 10uF; C0603_1
C21, C22: 22pF; C0603_1
C23, C24: 12.5pF; C0603_1
C32, C33: 2.2uF; C0603_1
CARD1: TF-01A; TF-SMD_TF-01A_1
D2: PESD3V3L1BA-N; SOD-323_L1.8-W1.3-LS2.5-BI_1
D3: BAT54C_C556168; SOT-23-3_L2.9-W1.3-P1.90-LS253
D5: 1N4007WS; SOD-323_L1.8-W1.3-LS2.5-RD_1
FPC1: F0502-B-40-20T-R; FPC-SMD_40P-P0.50_1
H1: ¶ЁО»їЧ; H1_1
H2: ¶ЁО»їЧ; H2_1
H3: ¶ЁО»їЧ; H3_1
H4: ¶ЁО»їЧ; H4_1
H5: 2.54-1*4P·ґНдЕЕХл; HDR-TH_4P-P2.54-H-M-W10.4_1
H6: MF254VS-12-20-0743; HDR-SMD_20P-P2.54-V-F-R2-C10E1
H7: MF254VS-12-20-0743; HDR-SMD_20P-P2.54-V-F-R2-C10E2
IMPORTED_IMAGE: Comment; IMPORTED_IMAGE_1
IMPORTED_IMAGE2, IMPORTED_IMAGE3: Comment; IMPORTED_IMAGE_2
L1: 1uH; IND-SMD_L2.5-W2.0_SLW252012PA9
L2, L3, L6: 330¦ё@100MHz; L0603_1
LED1, LED3: green; LED0603-R-RD_1
LED2: blue; LED0603-RD_1
Q1: SS8050; SOT-23-3_L2.9-W1.3-P1.90-LS250
Q2: SS8050; SOT-23-3_L2.9-W1.3-P1.90-LS251
R1: 200K; R0603_2
R2: 44.2K; R0603_2
R3, R11, R12, R29: 1K; R0603_2
R4, R5, R6, R7, R23: 10k; R0603_3
R8, R9, R15, R18: 10k; R0603_2
R10: 0R; R0603_2
R13, R14: 120R; R0603_2
R16, R17: 1k; R0603_2
R19: 499K; R0603_1
R20: 200K; R0603_1
R118, R119: 5K1; R0603_2
SW1, SW2, SW4: SKRKAEE020; SW-SMD_L3.9-W3.0-P4.45_1
U1: STM32H750VBT6; LQFP-100_L14.0-W14.0-P0.50-L8F
U2: MP2144GJ; TSOT-23-8_L2.9-W1.6-P0.65-LS99
U3: W25Q64JVSSIQ; SOP-8_L5.3-W5.3-P1.27-LS8.0-69
U4: W25Q64JVSSIQ; SOP-8_L5.3-W5.3-P1.27-LS8.0-6A
U5: CH340N; SOP-8_L5.0-W4.0-P1.27-LS6.0-A0
U7: SN74LVC2G17DBVR; SOT-23-6_L2.9-W1.6-P0.95-LS298
USB1, USB2: TYPE-C16PIN; USB-C-SMD_TYPE-C16PIN_1
X1: 25MHz; OSC-SMD_4P-L3.2-W2.5-BL_1
X2: 32.768KHz; OSC-SMD_L3.2-W1.5_1

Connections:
3V3: C1.2, C2.2, C3.2, C4.2, C5.2, C9.2, C10.2, C14.2, C15.2, C18.2, C20.2, CARD1.4, D2.2, D3.1, FPC1.6, FPC1.7, H7.1, L1.2, L3.1, LED2.2, R1.2, R3.1, R4.1, R5.1, R6.1, R7.1, R8.1, R9.2, R16.2, R17.2, R23.1, SW1.2, U1.11, U1.27, U1.50, U1.75, U1.100, U2.5, U3.8, U4.8, U7.5
5V_USB: C6.2, C7.1, C11.2, C13.2, FPC1.1, FPC1.2, H6.1, R19.1, R20.1, U2.2, USB1.A4B9, USB1.B4A9
BOOT0: LED3.1, Q2.2, R18.2, U1.94
C17_2: C16.2, C17.2, U5.5, USB2.A4B9, USB2.B4A9
C19_2: C19.2, U5.8
D5_1: C31.2, D5.1, Q2.1
FPC1_38: FPC1.38, R12.1
FPC1_39: FPC1.39, R13.1
FPC1_40: FPC1.40, R14.1
GND: C1.1, C2.1, C3.1, C4.1, C5.1, C6.1, C7.2, C9.1, C10.1, C11.1, C13.1, C14.1, C15.1, C16.1, C17.1, C18.1, C19.1, C20.1, C21.1, C22.1, C23.1, C24.1, C25.1, C26.1, C27.1, C28.1, C29.1, C30.1, C31.1, C32.1, C33.1, CARD1.6, CARD1.10, CARD1.11, CARD1.12, CARD1.13, D2.1, FPC1.4, FPC1.5, FPC1.12, FPC1.16, FPC1.20, FPC1.24, FPC1.28, FPC1.32, FPC1.36, H5.1, H6.2, H7.2, L2.2, L6.1, LED1.2, LED3.2, Q1.2, R2.1, R18.1, R118.2, R119.2, SW2.1, SW4.2, U1.10, U1.19, U1.26, U1.49, U1.74, U1.99, U2.4, U2.6, U3.4, U4.4, U5.3, U7.2, USB1.A1B12, USB1.B1A12, USB2.A1B12, USB2.B1A12, X1.2, X1.4
H5_4: H5.4, R11.1
KEYPC13: SW4.1, U1.7
L1_1: L1.1, U2.3
L2_1: L2.1, USB1.1, USB1.2, USB1.3, USB1.4
LCD_B2_PD6: FPC1.19, U1.87
LCD_B3_PD10: FPC1.18, U1.57
LCD_B4_PE12: FPC1.17, U1.42
LCD_B5_PA3: FPC1.15, U1.25
LCD_B6_PB8: FPC1.14, U1.95
LCD_B7_PB9: FPC1.13, U1.96
LCD_BL_PD15: FPC1.3, U1.62
LCD_CLK_PE14: FPC1.37, U1.44
LCD_DE_PE13: FPC1.9, U1.43
LCD_G2_PA6: FPC1.27, U1.30
LCD_G3_PE11: FPC1.26, U1.41
LCD_G4_PB10: FPC1.25, U1.46
LCD_G5_PB11: FPC1.23, U1.47
LCD_G6_PC7: FPC1.22, U1.64
LCD_G7_PD3: FPC1.21, U1.84
LCD_HS_PC6: FPC1.11, U1.63
LCD_R2_PA1: FPC1.35, U1.23
LCD_R3_PB0: FPC1.34, U1.34
LCD_R4_PA5: FPC1.33, U1.29
LCD_R5_PC0: FPC1.31, U1.15
LCD_R6_PB1: FPC1.30, U1.35
LCD_R7_PE15: FPC1.29, U1.45
LCD_VS_PA4: FPC1.10, H6.5, U1.28
LED1_1: LED1.1, R3.2
LEDPC1: H7.12, R29.1, U1.16
OS_25M_IN: C21.2, U1.12, X1.1
OS_25M_OUT: C22.2, U1.13, X1.3
OS_32K_IN: C23.2, U1.8, X2.1
OS_32K_OUT: C24.2, U1.9, X2.2
PA0: H6.3, U1.22
PA2: H6.4, U1.24
PA7: H6.6, U1.31
PA8: H7.14, U1.67
PB7: H7.6, U1.93
PB12: H6.18, U1.51
PB13: H6.19, U1.52
PB14: H6.20, U1.53
PB15: H6.17, U1.54
PC2: H6.9, U1.17
PC3: H6.10, U1.18
PC4: H6.7, U1.32
PC5: H6.8, U1.33
PD0: H7.11, U1.81
PD1: H7.10, U1.82
PD4: H7.9, U1.85
PD5: H7.8, U1.86
PD7: H7.7, U1.88
PD8: H6.16, U1.55
PD9: H6.15, U1.56
PD14: H7.13, U1.61
PE0: H7.5, U1.97
PE1: H7.4, U1.98
PE7: H6.11, U1.37
PE8: H6.12, U1.38
PE9: H6.13, U1.39
PE10: H6.14, U1.40
Q2_3: Q2.3, R17.1
QSPI_BK1_IO0PD11: U1.58, U3.5
QSPI_BK1_IO1PD12: U1.59, U3.2
QSPI_BK1_IO2PE2: U1.1, U3.3
QSPI_BK1_IO3PD13: U1.60, U3.7
QSPI_BK1_NCSPB6: U1.92, U3.1
QSPI_CLKPB2: U1.36, U3.6
R2_2: R1.1, R2.2, U2.7
R15_2: Q1.1, R15.2
R29_2: LED2.1, R29.2
R118_1: R118.1, USB1.A5
R119_1: R119.1, USB1.B5
RST: C30.2, Q1.3, R11.2, R16.1, SW2.2, U1.14
SDIO_CLKPC12: CARD1.5, H7.17, U1.80
SDIO_CMDPD2: CARD1.3, H7.18, R7.2, U1.83
SDIO_D0PC8: CARD1.7, H7.16, R23.2, U1.65
SDIO_D1PC9: CARD1.8, H7.15, R4.2, U1.66
SDIO_D2PC10: CARD1.1, H7.20, R5.2, U1.78
SDIO_D3PC11: CARD1.2, H7.19, R6.2, U1.79
SPI6_MISOPB4: U1.90, U4.2
SPI6_MOSIPB5: U1.91, U4.5
SPI6_NSSPA15: U1.77, U4.1
SPI6_SCKPB3: U1.89, U4.6
SW1_1: D5.2, R15.1, SW1.1
SWCLKPA14: H5.2, U1.76
SWDIOPA13: H5.3, U1.72
TOUCH_INT_PE4: R12.2, U1.3
TOUCH_RST_PE3: FPC1.8, U1.2
TOUCH_SCLK_PE5: R13.2, U1.4
TOUCH_SDA_PE6: R14.2, U1.5
U1_48: C32.2, U1.48
U1_73: C33.2, U1.73
U2_1: R20.2, U2.1
U2_8: R19.2, U2.8
U4_3: R8.2, U4.3
U4_7: R9.1, U4.7
U5_6: U5.6, U7.3
U5_7: U5.7, U7.6
UD+: U5.1, USB2.A6, USB2.B6
UD-: U5.2, USB2.A7, USB2.B7
USART1-RXPA10: U1.69, U7.4
USART1-TXPA9: U1.68, U7.1
USB2_1: L6.2, USB2.1, USB2.2, USB2.3, USB2.4
USB_D+: U1.71, USB1.A6, USB1.B6
USB_D-: U1.70, USB1.A7, USB1.B7
VBAT: C29.2, D3.3, U1.6
VBT: D3.2, H7.3
VDDA: C25.2, C26.2, L3.2, R10.1, U1.21
VREF: C27.2, C28.2, R10.2, U1.20

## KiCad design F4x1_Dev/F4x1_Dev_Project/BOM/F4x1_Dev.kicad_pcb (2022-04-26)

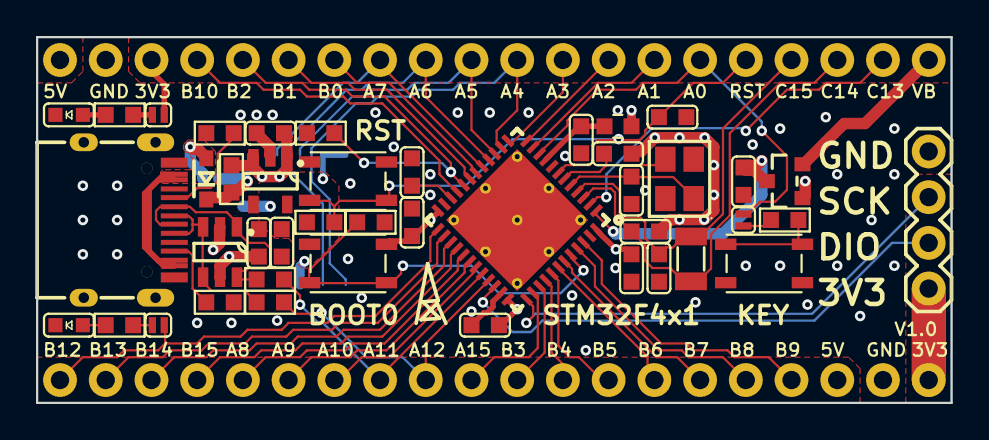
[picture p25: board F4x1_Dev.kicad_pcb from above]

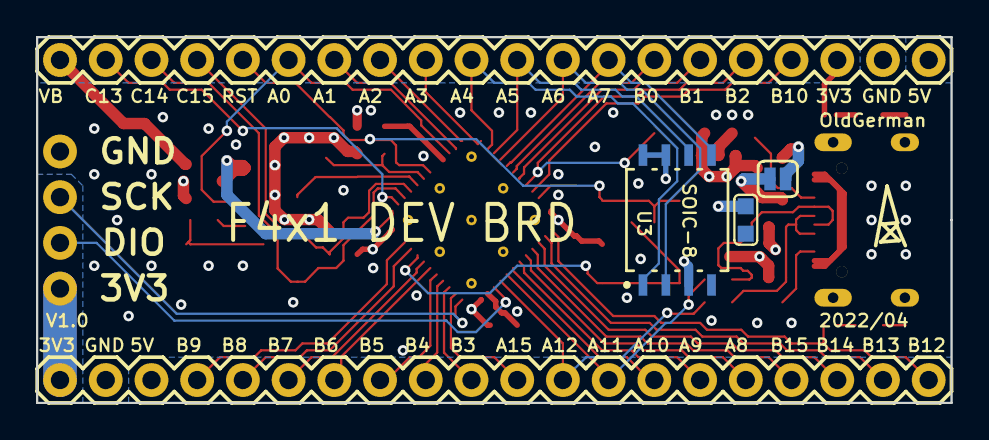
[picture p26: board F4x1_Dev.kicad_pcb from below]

Board: 4 copper layers, 50.8 x 20.3 mm, 50 parts (6 on the bottom side), 57 nets.

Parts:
*1, *2: ODG_LOGO; ODG_LOGO_1
C1, C4, C5, C6, C9, C14, C15: 100nF; C0603_1
C2, C3: 1uF/X7R; C0603_1
C7: 100nF; C0603_2
C8, C10: 6pF; C0603_1
C11, C13: 10pF; C0603_1
C12: 2.2uF; C0603_1
D1: B5819W; SOD-323_1
F1: 6V/0.5A; FUSE0603_0.5MM_1
L1: 10uH; FER0603_1
LED1: LED; LED0603_GREEN_1
LED2: LED; LED0603_YELLOW_1
P1, P2: CONN_X20; 2.54MM_MALE_X20_1
P3: CONN_X4; 2.54mm_Male_x4_1
R1, R2, R3, R4: 5.1K; R0603_1
R5, R6: 22R; R0603_1
R7: 330R; R0603_1
R8, R9, R10: 10K; R0603_1
SJ1: SJ_2P; SJ_2P_1
SJ2, SJ3, SJ4: SJ_2P; SJ_2P_MINI_1
SW1, SW2, SW3: Button-4P; SWITCH_3X4X2.5_4PIN_SMD_1
U1: STM32F4x1CxU6; UFQFPN-48_7X7X0P55MM_VIA_1
U2: ME6211C33M5G; ANALOG_TSOT-23-5_UJ-5_1
U3: W25Q32JVSSIQ; WIN_SS-8_WIN-L_1
USB1: Type-C; Type-C-TOP_1
VD1: BAT54C; ON_SEMI_SOT-23-3_1
VD2: USBLC6-2; MICROCHIP_SOT-23-6_M6_1
X1: 32.768KHz; XTAL_2P_3215_1
X2: 8MHz; EPSON_TSX-3225_1

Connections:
+3V3: C3.2, C4.2, C5.1, C6.1, C15.2, L1.1, P1.20, P2.3, P3.1, R9.1, SJ2.1, SW3.3, SW3.4, U1.24, U1.36, U1.48, U2.5, U3.3, U3.7, U3.8, VD1.1
+5: D1.1, SJ1.1, USB1.A4, USB1.A9, USB1.B4, USB1.B9
BOOT0: R10.1, SW3.1, SW3.2, U1.44
D+: R6.1, USB1.A6, USB1.B6, VD2.3, VD2.4
D-: R5.1, USB1.A7, USB1.B7, VD2.1, VD2.6
F_CS: P2.11, U1.14, U3.1
GND: C1.2, C2.1, C3.1, C4.1, C5.2, C6.2, C7.1, C8.2, C9.1, C10.2, C11.2, C12.1, C13.2, C14.1, C15.1, LED1.2, LED2.2, P1.19, P2.2, P3.4, R1.1, R3.2, R8.2, R10.2, SW1.3, SW1.4, SW2.1, SW2.2, U1.8, U1.23, U1.35, U1.47, U1.49, U1.49_1, U1.49_2, U1.49_3, U1.49_4, U1.49_5, U1.49_6, U1.49_7, U1.49_8, U1.49_9, U2.2, U3.4, USB1.1, USB1.2, USB1.3, USB1.4, USB1.A1, USB1.A12, USB1.B1, USB1.B12, VD2.2, X2.2, X2.4
MISO: P2.9, U1.16, U3.2
MOSI: P2.8, U1.17, U3.5
NRST: C14.2, P2.16, R9.2, SW2.3, SW2.4, U1.7
NetC12_2: C12.2, U1.22
NetD1_2: D1.2, F1.1, SJ1.2
NetLED1_1: LED1.1, R2.2
NetLED2_1: LED2.1, R4.2
NetR1_2: R1.2, USB1.A5
NetR2_1: R2.1, SJ2.2
NetR3_1: R3.1, USB1.B5
NetR4_1: R4.1, SJ3.2
NetR7_1: R7.1, SW1.1, SW1.2
NetR7_2: R7.2, SJ4.2
PA0: P2.15, SJ4.1, U1.10
PA1: P2.14, U1.11
PA2: P2.13, U1.12
PA3: P2.12, U1.13
PA5: P2.10, U1.15, U3.6
PA8: P1.5, U1.29
PA9: P1.6, U1.30
PA10: P1.7, U1.31
PA11: P1.8, R5.2, U1.32
PA12: P1.9, R6.2, U1.33
PA13: P3.2, U1.34
PA14: P3.3, U1.37
PA15: P1.10, U1.38
PB0: P2.7, U1.18
PB1: P2.6, U1.19
PB2: P2.5, R8.1, U1.20
PB3: P1.11, U1.39
PB4: P1.12, U1.40
PB5: P1.13, U1.41
PB6: P1.14, U1.42
PB7: P1.15, U1.43
PB8: P1.16, U1.45
PB9: P1.17, U1.46
PB10: P2.4, U1.21
PB12: P1.1, SJ3.1, U1.25
PB13: P1.2, U1.26
PB14: P1.3, U1.27
PB15: P1.4, U1.28
PC13: P2.19, U1.2
PC14: C8.1, P2.18, U1.3, X1.1
PC15: C10.1, P2.17, U1.4, X1.2
PH0: C11.1, U1.5, X2.1
PH1: C13.1, U1.6, X2.3
VB: P2.20, VD1.2
VBAT: C1.1, U1.1, VD1.3
VCC: C2.2, C9.2, F1.2, P1.18, P2.1, U2.1, U2.3, VD2.5
VREF+: C7.2, L1.2, U1.9

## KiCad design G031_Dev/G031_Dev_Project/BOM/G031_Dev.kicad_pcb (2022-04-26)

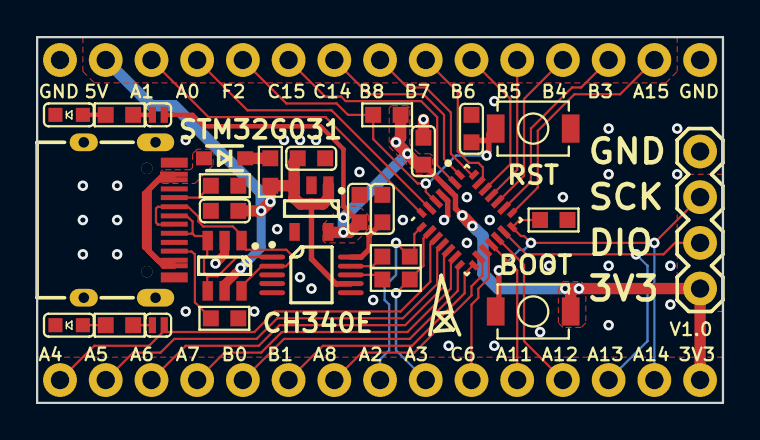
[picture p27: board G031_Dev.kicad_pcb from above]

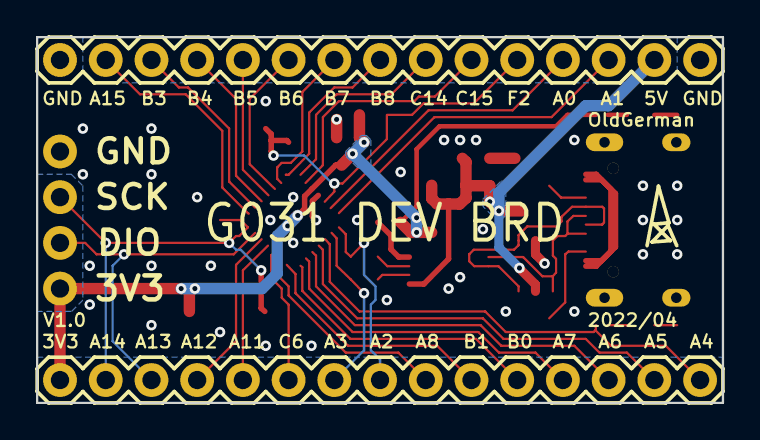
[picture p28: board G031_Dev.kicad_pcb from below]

Board: 2 copper layers, 38.1 x 20.3 mm, 32 parts (3 on the bottom side), 42 nets.

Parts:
*, *2: ODG_LOGO; ODG_LOGO_1
C1, C3, C4: 100nF; C0603_1
C2: 1uF/X7R; C0603_2
C5, C6: 1uF/X7R; C0603_1
D1: B5819W; SOD-323_1
F1: 6V/0.5A; FUSE0603_0.5MM_1
LED1: LED; LED0603_GREEN_1
LED2: LED; LED0603_YELLOW_1
P1: CONN_X4; 2.54mm_Male_x4_1
P2, P3: CONN_X15; 2.54MM_MALE_X15_1
R1, R2, R3, R8: 5.1K; R0603_1
R4, R5: 470R; R0603_1
R6, R7: 10K; R0603_1
SJ1, SJ2: SJ_2P; SJ_2P_MINI_1
SW1, SW2: Button-2P; SWITCH_3X4_SMD_1
U1: STM32G031G8U6; UFQFPN28-4x4mm_ODG_1
U2: CH340E; TI_MSOP-10_DGS_1
U3: ME6211C33M5G; ANALOG_TSOT-23-5_UJ-5_1
USB1: Type-C; Type-C-TOP_1
VD1: USBLC6-2; MICROCHIP_SOT-23-6_M6_1

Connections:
+3V3: C2.1, C6.2, P1.1, P2.15, R6.1, SJ1.1, SW1.2, U1.3, U3.5
+5: D1.1, USB1.A4, USB1.A9, USB1.B4, USB1.B9
CH340E_RX: R5.1, U2.9
CH340E_TX: R4.1, U2.8
D+: U2.1, USB1.A6, USB1.B6, VD1.3, VD1.4
D-: U2.2, USB1.A7, USB1.B7, VD1.1, VD1.6
GND: C1.1, C2.2, C3.1, C4.1, C5.1, C6.1, LED1.2, LED2.2, P1.4, P3.1, P3.15, R2.1, R3.2, R7.2, SW2.1, U1.4, U2.3, U3.2, USB1.1, USB1.2, USB1.3, USB1.4, USB1.A1, USB1.A12, USB1.B1, USB1.B12, VD1.2
NetC1_2: C1.2, U2.10
NetD1_2: D1.2, F1.1
NetLED1_1: LED1.1, R1.2
NetLED2_1: LED2.1, R8.2
NetR1_1: R1.1, SJ1.2
NetR2_2: R2.2, USB1.A5
NetR3_1: R3.1, USB1.B5
NetR8_1: R8.1, SJ2.2
PA0: P3.4, U1.6
PA1: P3.3, U1.7
PA2_TX: P2.8, R5.2, U1.8
PA3_RX: P2.9, R4.2, U1.9
PA4: P2.1, SJ2.1, U1.10
PA5: P2.2, U1.11
PA6: P2.3, U1.12
PA7: P2.4, U1.13
PA8: P2.7, U1.16
PA11: P2.11, U1.18
PA12: P2.12, U1.19
PA13_SWDIO: P1.2, P2.13, U1.20
PA14_SWCLK_B_O_O_T_0_: P1.3, P2.14, R7.1, SW1.1, U1.21
PA15: P3.14, U1.22
PB0: P2.5, U1.14
PB1: P2.6, U1.15
PB3: P3.13, U1.23
PB4: P3.12, U1.24
PB5: P3.11, U1.25
PB6: P3.10, U1.26
PB7: P3.9, U1.27
PB8: P3.8, U1.28
PC6: P2.10, U1.17
PC14: P3.7, U1.1
PC15: P3.6, U1.2
PF2_N_R_S_T_: C4.2, P3.5, R6.2, SW2.2, U1.5
VCC: C3.2, C5.2, F1.2, P3.2, U2.7, U3.1, U3.3, VD1.5

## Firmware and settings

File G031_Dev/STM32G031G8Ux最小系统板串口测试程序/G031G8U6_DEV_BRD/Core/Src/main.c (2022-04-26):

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
/* Includes ------------------------------------------------------------------*/
#include "main.h"

I2C_HandleTypeDef hi2c1;
I2C_HandleTypeDef hi2c2;

SPI_HandleTypeDef hspi1;

UART_HandleTypeDef huart2;

/* USER CODE BEGIN PV */
uint8_t key;
uint8_t len;
uint8_t times = 0;
/* USER CODE END PV */

void SystemClock_Config(void);
static void MX_GPIO_Init(void);
static void MX_USART2_UART_Init(void);
static void MX_I2C1_Init(void);
static void MX_I2C2_Init(void);
static void MX_SPI1_Init(void);
/**
  * @brief  The application entry point.
  * @retval int
  */
int main(void)
{
  /* MCU Configuration--------------------------------------------------------*/

  /* Reset of all peripherals, Initializes the Flash interface and the Systick. */
  HAL_Init();

  /* Configure the system clock */
  SystemClock_Config();

  /* Initialize all configured peripherals */
  MX_GPIO_Init();
  MX_USART2_UART_Init();
  MX_I2C1_Init();
  MX_I2C2_Init();
  MX_SPI1_Init();
  /* Infinite loop */
  /* USER CODE BEGIN WHILE */
  HAL_GPIO_WritePin(LED_GPIO_Port, LED_Pin, GPIO_PIN_RESET);
  while (1)
  {
//	  HAL_GPIO_WritePin(LED_GPIO_Port, LED_Pin, !HAL_GPIO_ReadPin(LED_GPIO_Port, LED_Pin));
//	  HAL_Delay(500);
    /* USER CODE END WHILE */

    /* USER CODE BEGIN 3 */
      if(USART_RX_STA&0x8000)
		{
			len=USART_RX_STA&0x3fff;//得到此次接收到的数据长度
			printf("\r\n您发送的消息为::\r\n");
			HAL_UART_Transmit(&huart2,(uint8_t*)USART_RX_BUF,len,1000);//发送接收到的数据
			while(__HAL_UART_GET_FLAG(&huart2,UART_FLAG_TC)!=SET);//等待发送结束
			printf("\r\n\r\n");//插入换行
			USART_RX_STA = 0;
		}
		else
		{
			times++;

			if (times % 5000 == 0)
			{
				printf("\r\nALIENTEK 战舰 STM32开发板 串口实验\r\n");
				printf("正点原子@ALIENTEK\r\n\r\n\r\n");
			}
			if (times % 200 == 0)
				printf("请输入数据,以回车键结束\r\n");
			if (times % 30 == 0)
				HAL_GPIO_WritePin(LED_GPIO_Port, LED_Pin, !HAL_GPIO_ReadPin(LED_GPIO_Port, LED_Pin));		//闪烁LED,提示系统正在运行..
			HAL_Delay(10);
		}
  }
  /* USER CODE END 3 */
}

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


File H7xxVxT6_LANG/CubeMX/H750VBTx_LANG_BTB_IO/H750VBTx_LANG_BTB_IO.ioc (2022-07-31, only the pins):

Mcu.UserName=STM32H750VBTx
PA0.Signal=GPIO_Output
PA2.Signal=GPIO_Output
PA4.Signal=COMP_DAC11_group
PA7.Signal=GPIO_Output
PA8.Signal=GPIO_Output
PB12.Signal=GPIO_Output
PB13.Signal=GPIO_Output
PB14.Signal=GPIO_Output
PB15.Signal=GPIO_Output
PB7.Signal=GPIO_Output
PC1.Signal=GPIO_Output
PC10.Signal=GPIO_Output
PC11.Signal=GPIO_Output
PC12.Signal=GPIO_Output
PC3_C.Signal=GPIO_Output
PC4.Signal=GPIO_Output
PC5.Signal=GPIO_Output
PC8.Signal=GPIO_Output
PC9.Signal=GPIO_Output
PD0.Signal=GPIO_Output
PD1.Signal=GPIO_Output
PD14.Signal=GPIO_Output
PD2.Signal=GPIO_Output
PD4.Signal=GPIO_Output
PD5.Signal=GPIO_Output
PD7.Signal=GPIO_Output
PD8.Signal=GPIO_Output
PD9.Signal=GPIO_Output
PE0.Signal=GPIO_Output
PE1.Signal=GPIO_Output
PE10.Signal=GPIO_Output
PE7.Signal=GPIO_Output
PE8.Signal=GPIO_Output

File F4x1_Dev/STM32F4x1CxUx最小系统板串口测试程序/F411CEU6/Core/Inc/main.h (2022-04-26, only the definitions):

#define KEY_Pin GPIO_PIN_0
#define KEY_GPIO_Port GPIOA
#define LED_Pin GPIO_PIN_12
#define LED_GPIO_Port GPIOB

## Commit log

2022-04-27 删除多余的history文件
2022-07-31 添加 H7xxVxT6_LANG 开发板
    [G031_Dev.PcbDoc]
2022-07-31 修改README
2022-07-31 添加H750VBTx_LANG_BTB_IO.ioc，标记双排母引出的io
2022-07-31 添加H750VBTx_LANG双排母引出的io图片
2022-07-31 添加H750VBTx_LANG双排母引出的io图片x2
2022-08-04 H7xxVxT6_LANG添加BOM
    [BOM_STM32H750VBT6核心板_仿制反客科技_yydsdx_2022-08-04.csv, PCB_STM32H750VBT6_GFX_2022-08-04.kicad_pcb]

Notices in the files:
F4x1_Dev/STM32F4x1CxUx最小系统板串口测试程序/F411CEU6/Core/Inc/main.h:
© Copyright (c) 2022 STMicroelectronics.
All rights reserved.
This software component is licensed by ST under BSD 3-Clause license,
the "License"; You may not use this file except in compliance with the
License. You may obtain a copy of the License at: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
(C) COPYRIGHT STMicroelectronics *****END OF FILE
